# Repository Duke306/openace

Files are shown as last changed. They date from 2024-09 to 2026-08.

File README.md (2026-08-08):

# GATAS Conspicuity Device




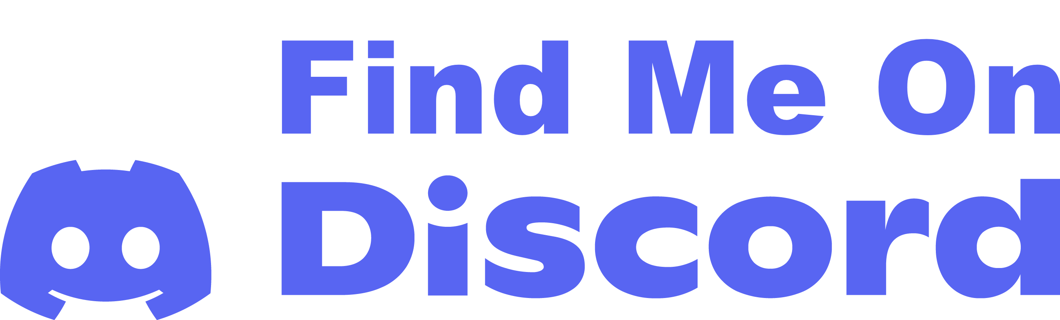
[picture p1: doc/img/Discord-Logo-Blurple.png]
[](https://discord.gg/J6mXTcWndS)

[📋 Changelog](./CHANGELOG.md) | [🎯 Wiki](https://rvt.github.io/gatas-doc/)

The GATAS Conspicuity device is designed for General Aviation pilots flying in areas where multiple
protocols, such as OGN, Flarm, ADS-L and FANET, are used. It can transmit and receive multiple
protocols simultaneously (excluding sending ADS-B) using one or more transceiver modules. All
received traffic is sent to your Electronic Flight Bag (EFB), such as SkyDemon, via the GDL90
protocol via WIFI or NMEA via bluetooth or WIFI.

The device is built around the Raspberry RP2040/RP2350 and can be configured with a custom PCB that
supports either two transceivers or a simpler configuration with one with modules from Waveshare
which makes it more of a plug-and-play. In both setups, it can send and receive all protocols using
time-sharing technology. The device can store configurations for multiple aircraft, which can be
selected through an easy-to-use web interface or via gatasServer

Powered by a Li-Ion battery, the device includes a PCB with a USB-C charger. The estimated battery
life is between 6 and 10 hours, though this is subject to further testing.

For FLARM it's current range has been t ested up to 24Km (see below screenshots) but on average a
good 15Km can be expected. This will give you plenty of time to avoid the traffic. EFBs like
SkyDemon can also send out audible traffic warnings.

Note: Although it's primary design is based around GA traffic, there is nothing in the hardware to
prevent other use cases like gliders, paragliders and hang gliders. The goal of the project is to be
seen by transmitting different protocols and be able to see them.

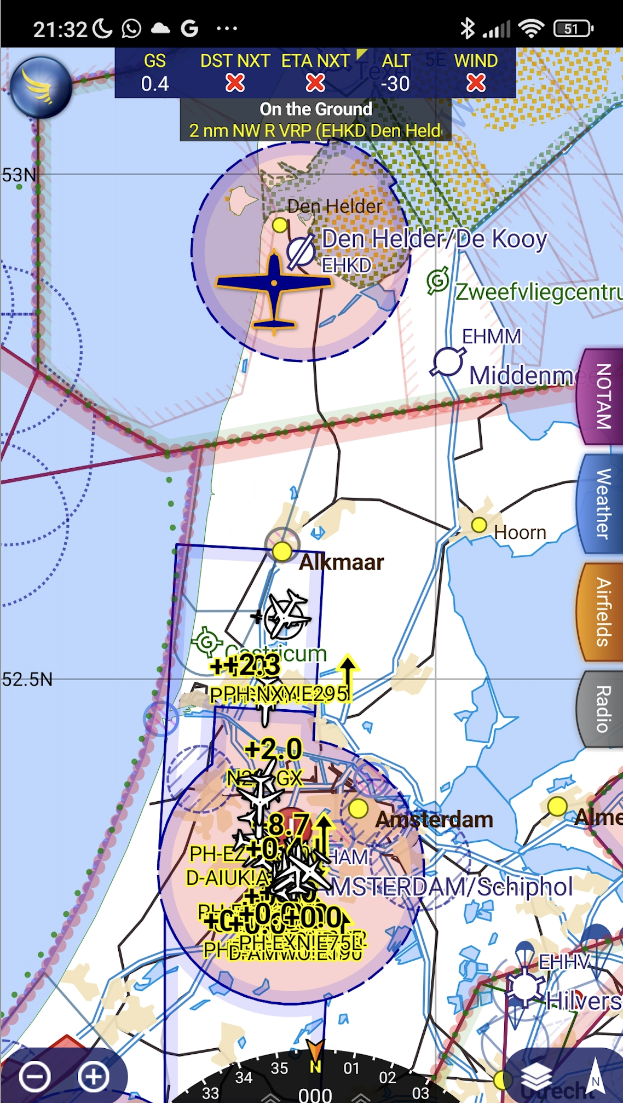
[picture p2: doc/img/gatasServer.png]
GATAS Server
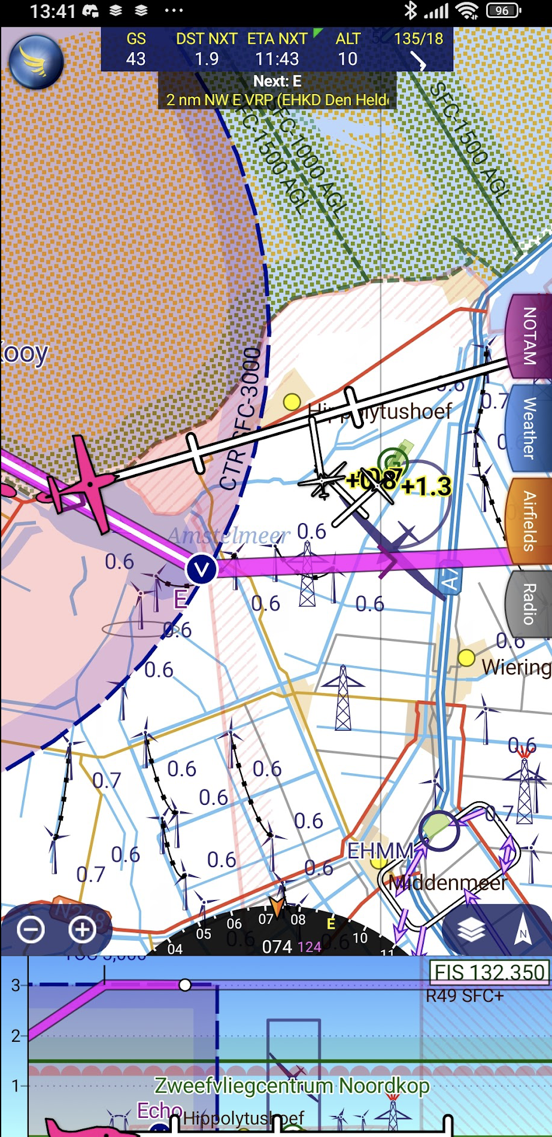
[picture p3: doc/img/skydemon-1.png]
Sky Demon)
| <br>Additional traffic via gatasServer |  <br> soaring planes directly via FLARM |
|---|---|
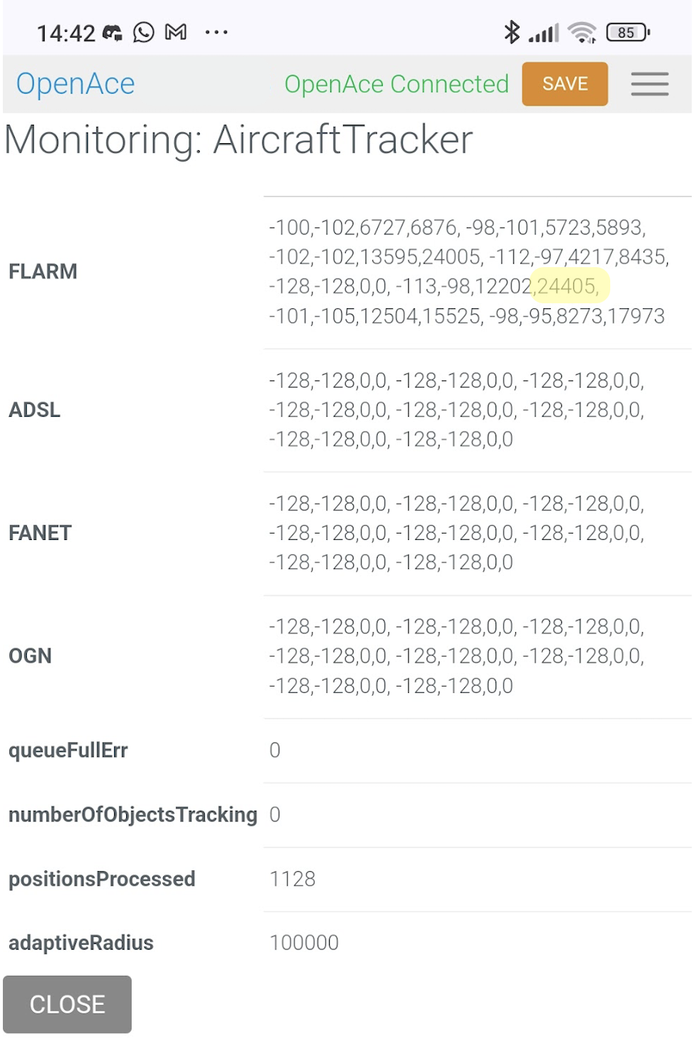
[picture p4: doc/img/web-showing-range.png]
Showing Range
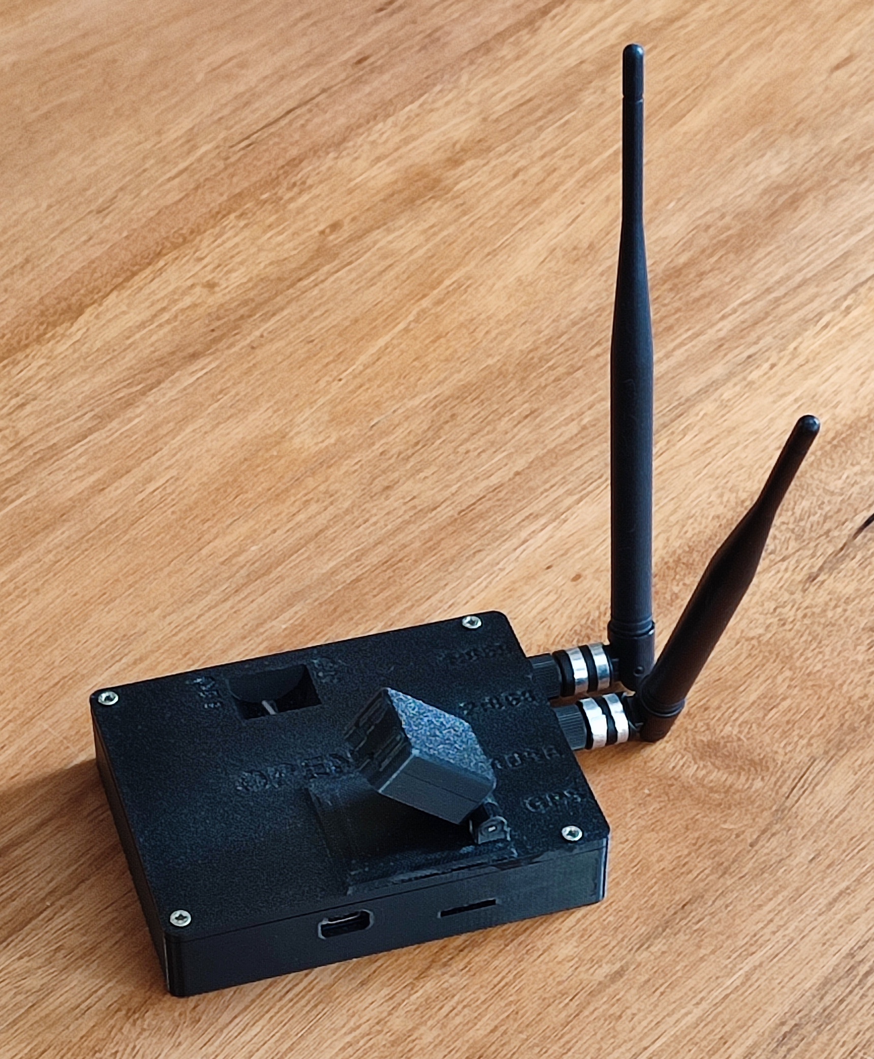
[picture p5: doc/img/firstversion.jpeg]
|  Showing range of 24Km | <br> Two Tranceiver Version I have been flying with |
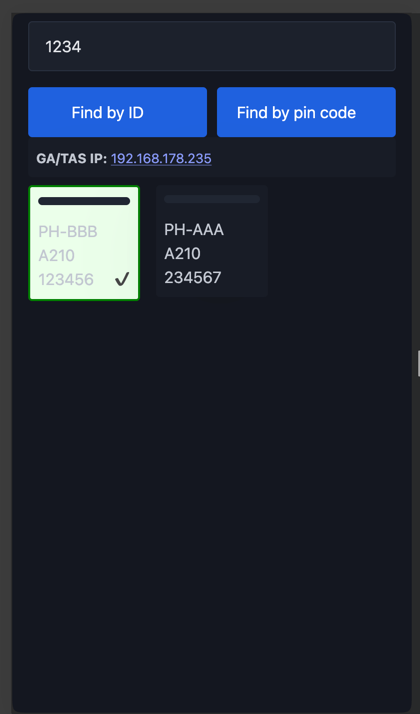
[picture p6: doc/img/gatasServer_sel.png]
Gatas Server
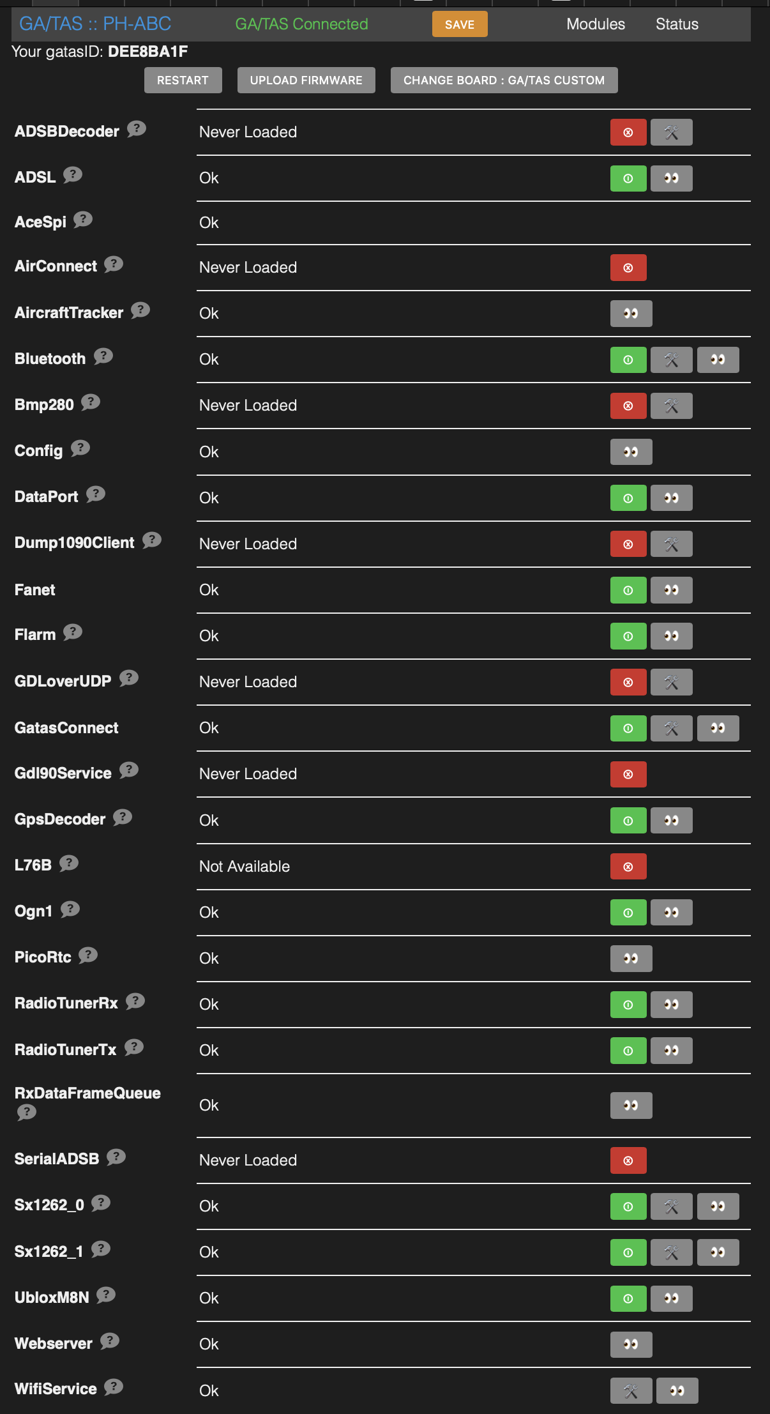
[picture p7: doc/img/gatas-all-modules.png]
All modules
|  <br> GATAS Server selecting Aircraft |  <br> All modules |
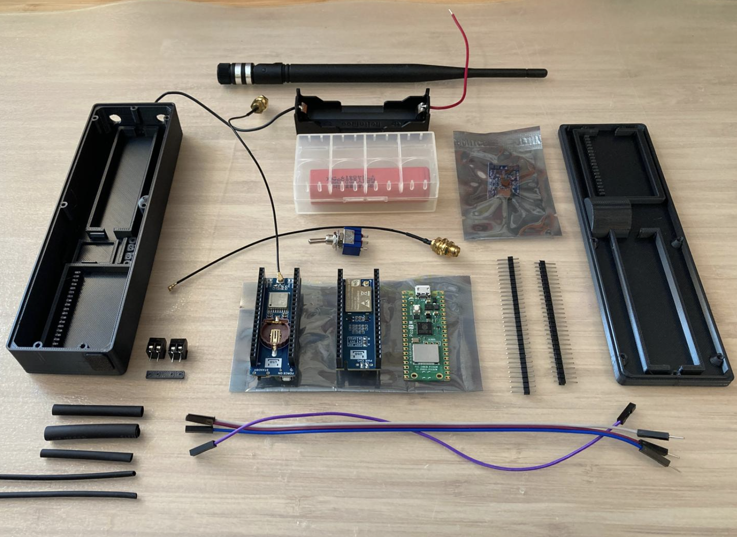
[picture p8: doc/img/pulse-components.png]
GATAS Pulse
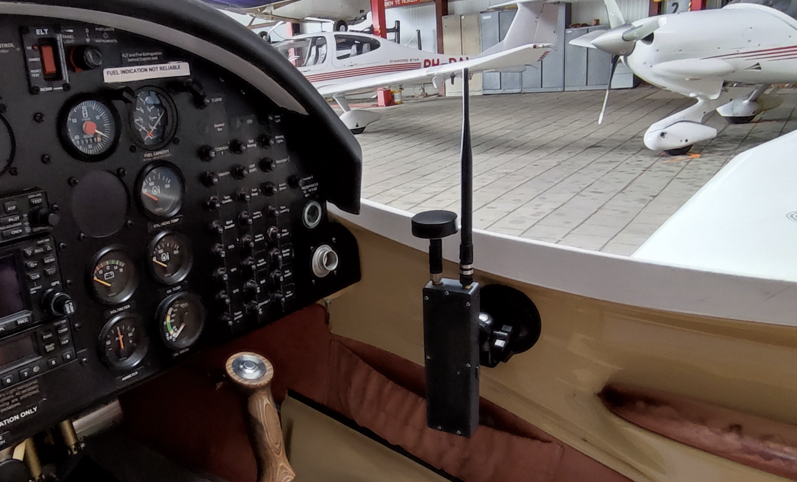
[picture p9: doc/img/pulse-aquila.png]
GATAS Pulse
|   <br> [GATAS Pulse Build Instructions](https://github.com/rvt/openace/wiki/gatas-Pulse) |  <br/> GATAS Pulse |

> [!NOTE]
> The screenshot of SkyDemon was taken from the car while driving for safety reasons. The screenshot
> of the web interface showing the 24Km was taken while parked and the device placed on top of the
> car
> for better air-2-air visibility.

## ADS-L Issue 2 — Ground Station Mode & Traffic Uplink

**New in 2.0.0**: GATAS now supports **ADS-L Issue 2** including ground station mode and traffic uplink. In ground
station mode the device not only transmits its own position but also re-broadcasts received traffic
back into the ADS-L network as uplink frames, making nearby traffic visible to other ADS-L
participants that would otherwise be out of range. This includes any traffic received via Gatas Connect and thus showing additional MLAT traffic.
This is ideal if you have glider fields and want to inform nearby traffic that a fields is active.
A maximum of 10 aircraft closest to the groundstation will be relayed.

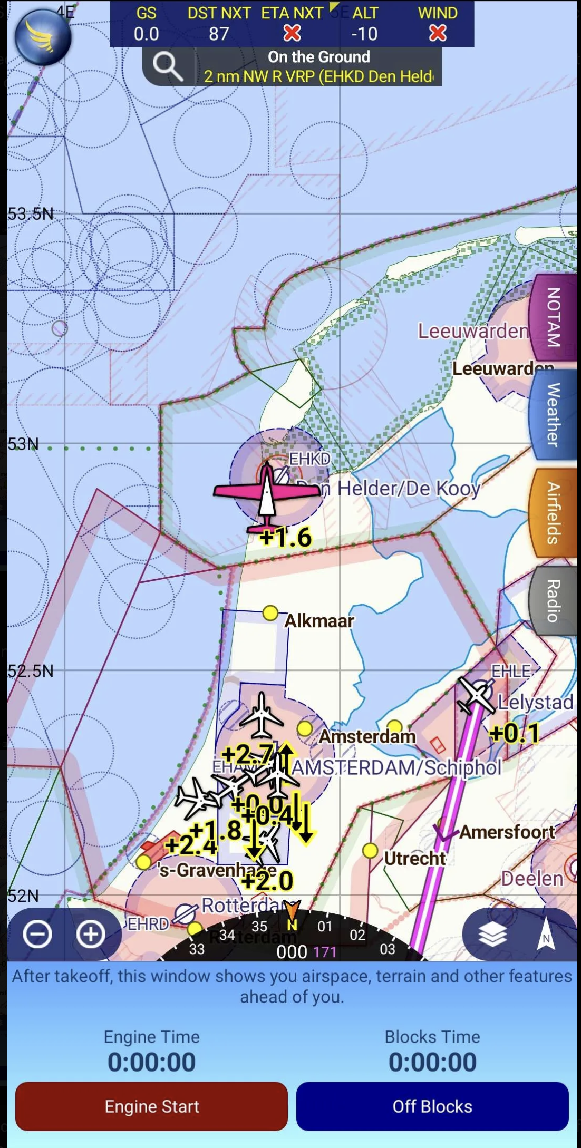
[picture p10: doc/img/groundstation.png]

Base station mode is active and relaying additional traffic.

## Radio Protocol Support

Radio Protocol is the method used to communicate with other conspicuity devices

| Radio Protocol. | Send | Receive | Multi Protocol |
|---|---|---|---|
| OGN | :heavy_check_mark: | :heavy_check_mark: | :heavy_check_mark: |
| ADS-L | :heavy_check_mark: | :heavy_check_mark: | :heavy_check_mark: |
| FLARM (2024) | :heavy_check_mark: | :heavy_check_mark: | :heavy_check_mark: |
| FANET | :heavy_check_mark: | :heavy_check_mark: | :heavy_check_mark: |
| ADS-B via gatasConnect | :no_entry: | :heavy_check_mark: | :heavy_minus_sign: |
| PAW (2026 uses ADS-L)  | :heavy_check_mark: | :heavy_check_mark: | :heavy_check_mark: |

\* Multi Protocol is a feature of GATAS that allows to enable multiple protocols both send and
receive on a single transceiver by sharing the air time. The Transceiver will alternate between the
different protocols and prioritize a specific protocol when it receives data for that protocol.

**Adaptive Protocol Prioritisation (New in 2.0.0)**: GATAS now intelligently allocates more listening slots
for protocols that are actively receiving traffic, increasing pings per aircraft and improving overall situational awareness.

- Fanet support sending and receving including forwaring of FANET messages
- gatasConnect is a protocol and service to receive additional traffic information via mobile
  connection.

\* PAW legacy protocol is not supported, only their new ADS-L version

### Communication support

Communication support is what protocols are supported to other devices like electronic flight bags
or other equipment.

| Protocol | Send UDP over WIFI | Receive UDP over WIFI | Send Bluetooth | Send TCP over WIFI | Receiver over TCP WIFI |
|---|---|---|---|---|---|
| GDL90 | :heavy_check_mark: | N/A | N/A | N/A | N/A |
| AirConnect | N/A | N/A | :heavy_check_mark: | :heavy_check_mark: | N/A |
| Dump1090 | N/A | N/A | N/A | N/A | :heavy_check_mark: |
| gatasConnect | :heavy_check_mark: | :heavy_check_mark: | N/A | N/A | :heavy_check_mark: |

\* Sending GDL90 over Bluetooth is not used in the industry so this is currently not setup. If this
is really required, then this can be done. Do let me know the use case

### Tested with Electronic Flight Bag

GATAS is currently tested with SkyDemon only, If you made it work with any other software on Phone
or Tablet, do let me know so I can add or help out to make this work.

| EFB | GDL90 over WIFI | Bluetooth | DataPort (NMEA) WIFI | Note |
|---|---|---|---|---|
| SkyDemon | :heavy_check_mark: | :heavy_check_mark: | :heavy_check_mark: | Tested Frequently during flight |
| EasyVFR 4 | :heavy_check_mark: | | | |
| ForeFlight | :heavy_check_mark: | | | With part of ForeFLight extended spec and auto discovery |
| XTrack | | :heavy_check_mark: | | Tested for connectivity |
| Air navigation | :heavy_check_mark: | | | Tested for connectivity |
| SeeYou Navigator | | :heavy_check_mark: | | GPS and traffic targets shown |

> [!INFO]
> Thanks to  [PocketFMS / EasyVFR](https://easyvfr4.aero/nl/) for providing a Developer license of EasyVFR 4 to help test GATAS GDL90
>

## gatasConnect & gatasServer

**gatasConnect** and **gatasServer** provide a lightweight UDP-based protocol for receiving
additional traffic information.
This is still somewhat experimental but up an running and usable, it's free for you to use on the pre-configured server. Just enable
'gatasConnect' and ensure GATAS does have internet access via your mobile dev ice. Configure **Client** mode to connect to
your mobile's access point, how cool is that!

> [!TIP]
> gatasConnect uses [https://airplanes.live](https://airplanes.live) to to deliver internet-based traffic to your GATAS
> and into your EFB, including ADS-B Out and MLAT-derived traffic.
> If you have the chance, please consider adding airplanes.live to your existing feed or creating a new one.
> By doing so, you help improve traffic coverage for yourself and for others and contribute to safer flying.
>

## Features

- Online web application to select your configured aircraft
- Eliminates the need to manually connect to GATAS vi WIFI to choose an aircraft, saves time and
  you can focus on flying.
- Still compatible with GATAS aircraft selection via **gatas build in web service**
- Future support for **automatic aircraft selection** based on correlated ADS-B traffic

### Network Usage

- **Transmit:** ~52 bytes/second
- **Receive:** ~1024 bytes/second at 30 aircraft. (supports up to 30 nearby aircraft)

## External Libraries and frameworks used

Most libraries are used 'as-is' Some of them have been slightly modified for performance reasons,
compatibility or other reasons.

1. Raspberry PI PICO
   SDK [https://github.com/raspberrypi/pico-sdk](https://github.com/raspberrypi/pico-sdk)
2. FreeRTOS, GATAS uses tasks and timers and avoids loops and runs in multi-core SMP
   mode. [https://www.freertos.org](https://www.freertos.org)
3. LWiP Pretty cool and sometimes confusing TCP/IP protocol
   suite [https://savannah.nongnu.org/projects/lwip/](https://savannah.nongnu.org/projects/lwip/)
4. ArduinoJSON for loading and storing
   configuration [https://arduinojson.org](https://arduinojson.org)
5. etlcpp pretty awesome library written by John
   Wellbelove [https://www.etlcpp.com](https://www.etlcpp.com)
6. libcrc [https://github.com/lammertb/libcrc](https://github.com/lammertb/libcrc)
7. minmea for parsing NMEA
   sentences [https://github.com/kosma/minmea/](https://github.com/kosma/minmea/)
8. Catch2 for unit testing [https://github.com/catchorg/Catch2](https://github.com/catchorg/Catch2)
8. Easy to use FANET implementation in
   C++ [https://github.com/rvt/FANET](https://github.com/rvt/FANET)

# GATAS Disclaimer

> [!IMPORTANT] > **Important Notice: Use at Your Own Risk**
>
> The GATAS Conspicuity Device is provided "as is," without any guarantees or warranties of any
> kind. By using this device, you acknowledge and agree that:
>
> 1. **No Warranty**: The creators of GATAS make no claims or guarantees regarding the accuracy,
     reliability, or fitness for a specific purpose of the device or its associated software. This
     includes, but is not limited to, communication with OGN, Flarm, ADS-L, or any other protocols.
> 2. **Assumption of Risk**: You assume full responsibility for any and all risks associated with
     the use of GATAS. This includes, but is not limited to, risks related to hardware
     malfunctions, software issues, or incorrect transmission/interpretation of data.
> 3. **Limitation of Liability**: Under no circumstances shall the creators, contributors, or
     affiliates of GATAS be held liable for any direct, indirect, incidental, or consequential
     damages resulting from the use, misuse, or inability to use the device or its software.
> 4. **General Aviation Use**: GATAS is intended for use in General Aviation environments where
     multiple protocols such as OGN, Flarm, and ADS-L are used. It is **not certified** for
     professional or commercial aviation use and should not be relied upon as the sole source of
     traffic or navigation information.
> 5. **Compliance**: Users are responsible for ensuring that the use of GATAS complies with local
     aviation regulations and requirements. It is your responsibility to ensure that the device
     operates within the legal limits and safety standards for your jurisdiction.
> 6. **IFR Use**: GATAS is not intended for usage during an IFR flight.
>
> By using GATAS, you agree to the terms of this disclaimer and acknowledge that you are using the
> device and its software at your own risk.

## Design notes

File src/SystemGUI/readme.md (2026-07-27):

# Overview

This directory, along with its subdirectories, contains the necessary files for developing components of the web interface for GATAS. If you're not working on the UI development, no additional steps are required—the C/C++ source files already integrate the web interface.

All files in the `SystemGUI/dist` directory are automatically packaged into `src/lib/webserver/gatas_fsdata.c`.

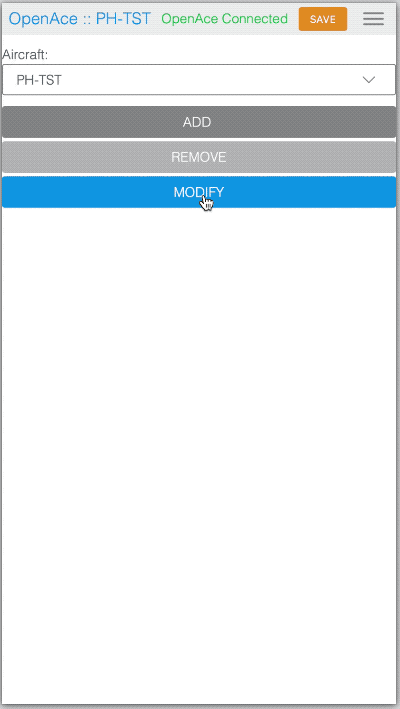
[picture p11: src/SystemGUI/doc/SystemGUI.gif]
GUI


# Libraries and frameworks used

1. `@frameable/el` LitElement-like framework to create and use web components [https://github.com/frameable/el](https://github.com/frameable/el)
1. `@picocss/pico` Lightweight semantic CSS framework, compiled with only the modules used by GATAS [https://picocss.com](https://picocss.com)
1. `just-validate` Form validation framework [https://just-validate.dev](https://just-validate.dev)

# Quick Start for UI Development

1. Ensure you have `npm` or `yarn` installed on your system, then run `npm install` in the `SystemGUI` directory.
2. Connect the GATAS hardware to your local network by enabling the `WifiService` and confgure GATAS to connect to your network
3. In the `.proxyrc.js` file, update the `target` variable with the device’s IP address. GATAS will print the IP address over Serial line USB or Debug mode
4. The UI will be accessible at `http://localhost:1234` if the device is running and connected to the network.
5. To start development, run `npm start`. Changes made to the code will be instantly reflected on the UI.
6. Once development is complete, run `npm run build` to generate a distribution in the `dist` directory. Rebuilding GATAS with `cmake` will include the necessary UI files.

# Unit Tests

1. Frontend unit tests live in `test/`.
2. Run tests with `npm test` from `src/SystemGUI`.
3. Add new tests using the `*.test.mjs` naming pattern.

# Files

- `.proxyrc.js` proxy setting to direct API calls to GATAS for hot re-loading en testing of the UI
- `.parcelrcrelease` Release configuration using in the build process to compress using gzip
- `package.json` npm package file
- `src` Directory containing the project files with css and various components

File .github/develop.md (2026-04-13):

# Development version {{VERSION}}

This is the **DEVELOPMENT** version of GATAS, use at your own risk

> [!TIP]
> **GATAS is an ongoing project** that is continuously being developed and improved.
> As a result, features, functionality, and performance may be updated or modified at any time without prior notice.
> We value feedback and collaboration!
> If you have any questions, suggestions, or concerns, feel free to reach out.
> Your input helps us improve the project and ensure it meets the needs of the community.

> [!IMPORTANT]
> **Disclaimer: Use at Your Own Risk**
>
> GATAS is provided "as is," without any warranties.
> By downloading or using this device, you acknowledge that you do so at your own risk.
> The creators are not liable for any damages or issues resulting from its use.
> GATAS is intended for General Aviation only and should not be relied upon as the sole source of traffic or navigation information.
> Users are responsible for ensuring compliance with local aviation regulations.

## In this release

{{CHANGELOG}}

## How to Copy the UF2 File to the Raspberry Pi Pico

### 1. Download the `GATAS_rp2040.uf2` or `GATAS_rp2350-arm-s.uf2` File
- Obtain the correct firmware suitable for your PICO from [https://github.com/rvt/openace/releases](https://github.com/rvt/openace/releases)
- Make sure you know where the file is saved on your computer.

### 2. Connect Raspberry Pi Pico to Your Computer
- **Hold down the BOOTSEL button** on your Raspberry Pi Pico.
- While holding the BOOTSEL button, **connect the Pico to your computer** using a USB cable.
- Once connected, release the BOOTSEL button.

### 3. Raspberry Pi Pico in USB Mass Storage Mode
- Your Pico will appear as a **USB mass storage device** on your computer (e.g., as `RPI-RP2`).
    - On **Windows**, it will appear as a removable drive.
    - On **macOS** and **Linux**, it will appear as an external drive.

### 4. Copy `GATAS_*.uf2` File to the Pico
- Open the `RPI-RP2` drive.
- **Drag and drop** or **copy and paste** the `GATAS_*.uf2` file into the Pico's drive.
    - Do **not** try to open or modify the `GATAS_*.uf2` file; simply copy it.

### 5. Automatic Reboot
- After the file is copied, the Pico will **automatically reboot** and run the new firmware.
- The Pico will disappear from your list of drives, indicating that the flashing process is complete.

### 6. Verify the Installation
- Once rebooted, the Pico will start running the newly flashed firmware, it should show a green flasing led

## Troubleshooting
- **If the Pico does not show up as a USB drive**:
    - Ensure you are holding the BOOTSEL button while connecting it to the computer.
    - Try using a different USB cable (some cables only provide power and don't support data transfer).

## Summary
1. Download the `GATAS_*.uf2` file.
2. Hold down the BOOTSEL button and connect the Pico to your computer.
3. Release the BOOTSEL button once connected.
4. Copy the `GATAS_*.uf2` file to the Pico's mass storage drive.
5. The Pico will reboot automatically, running the new firmware.
6. The green LED on the PICO will start flashing once a second

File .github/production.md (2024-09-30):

# Production version

This is the **PRODUCTION** version of OpenAce, use at your own risk

> [!TIP]
> **OpenAce is an ongoing project** that is continuously being developed and improved. 
> As a result, features, functionality, and performance may be updated or modified at any time without prior notice.
> We value feedback and collaboration! 
> If you have any questions, suggestions, or concerns, feel free to reach out. 
> Your input helps us improve the project and ensure it meets the needs of the community.

> [!IMPORTANT]
> **Disclaimer: Use at Your Own Risk**
> 
> OpenAce is provided "as is," without any warranties. 
> By downloading or using this device, you acknowledge that you do so at your own risk. 
> The creators are not liable for any damages or issues resulting from its use. 
> OpenAce is intended for General Aviation only and should not be relied upon as the sole source of traffic or navigation information. 
> Users are responsible for ensuring compliance with local aviation regulations.

## How to Copy the UF2 File to the Raspberry Pi Pico

### 1. Download the `OpenAce.uf2` File
- Obtain the `OpenAce.uf2` file from [https://github.com/rvt/OpenAce/release](https://github.com/rvt/OpenAce/release)
- Make sure you know where the file is saved on your computer.

### 2. Connect Raspberry Pi Pico to Your Computer
- **Hold down the BOOTSEL button** on your Raspberry Pi Pico.
- While holding the BOOTSEL button, **connect the Pico to your computer** using a USB cable.
- Once connected, release the BOOTSEL button.

### 3. Raspberry Pi Pico in USB Mass Storage Mode
- Your Pico will appear as a **USB mass storage device** on your computer (e.g., as `RPI-RP2`).
    - On **Windows**, it will appear as a removable drive.
    - On **macOS** and **Linux**, it will appear as an external drive.

### 4. Copy `OpenAce.uf2` File to the Pico
- Open the `RPI-RP2` drive.
- **Drag and drop** or **copy and paste** the `OpenAce.uf2` file into the Pico's drive.
    - Do **not** try to open or modify the `OpenAce.uf2` file; simply copy it.

### 5. Automatic Reboot
- After the file is copied, the Pico will **automatically reboot** and run the new firmware.
- The Pico will disappear from your list of drives, indicating that the flashing process is complete.

### 6. Verify the Installation
- Once rebooted, the Pico will start running the newly flashed firmware, it should show a green flasing led

## Troubleshooting
- **If the Pico does not show up as a USB drive**:
    - Ensure you are holding the BOOTSEL button while connecting it to the computer.
    - Try using a different USB cable (some cables only provide power and don't support data transfer).

## Summary
1. Download the `OpenAce.uf2` file.
2. Hold down the BOOTSEL button and connect the Pico to your computer.
3. Release the BOOTSEL button once connected.
4. Copy the `OpenAce.uf2` file to the Pico's mass storage drive.
5. The Pico will reboot automatically, running the new firmware.
6. The green LED on the PICO will start flashing once a second

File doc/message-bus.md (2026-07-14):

# OpenAce Message Bus

This document maps every message type to its sender(s) and receiver(s).

> **Maintenance note**: Keep this document split into separate flow diagrams. When updating it, change only the affected flow sections and do not collapse everything into one large combined flow unless explicitly asked.

> **How this was generated**: Senders were found by grepping `getBus().receive(` across all `.cpp` files. Receivers were found by grepping `void on_receive(const GATAS::` across all `.hpp` files. The class name was inferred from the enclosing file/class context.

> **Direct handoff note**: Some important current flows are shown even though they are not plain bus publishes, notably `Dump1090Client -> ADSBDecoder` and `Sx1262 -> RxDataFrameQueue`.

## Bus Semantics

- The firmware uses `GATAS::ThreadSafeBus<24>` from `src/lib/core/ace/messagerouter.hpp`.
- Dispatch is synchronous: publishers call `getBus().receive(...)` and the ETL bus delivers directly to subscribers.
- The bus itself does not queue or copy messages.
- `etl::shared_message` is technically supported but explicitly warned against.
- Some important data paths are not bus messages at all; those are called out below.

## Module Topology

```plantuml
' =====================================================================
' SYSTEM OVERVIEW
' =====================================================================
@startuml
title System Overview

left to right direction

rectangle "GPS Subsystem" {
    [AbstractGnss]
    [GpsDecoder]
}

rectangle "Radio Subsystem" {
    [Sx1262]
    [RxDataFrameQueue]
    [RadioTunerRx]
    [RadioTunerTx]
}

rectangle "ADSB Input" {
    [Dump1090Client]
}

rectangle "Protocols" {
    [Ogn1]
    [Flarm2024]
    [ADSLAce]
    [FanetAce]
    [ADSBDecoder]
}

rectangle "Tracking" {
    [AircraftTracker]
}

rectangle "Outputs" {
    [Gdl90Service]
    [GDLoverUDP]
    [DataPort]
    [GatasConnect]
    [GatasConnectUDP]
    [Bluetooth]
    [AirConnect]
}

rectangle "Infrastructure" {
    [Idle]
    [Config]
    [WifiService]
    [Bmp280]
    [PicoRtc]
}

[AbstractGnss] --> [GpsDecoder] : GPSSentenceMsg
[GpsDecoder] --> [Ogn1] : OwnshipPositionMsg
[GpsDecoder] --> [Flarm2024] : OwnshipPositionMsg
[GpsDecoder] --> [ADSLAce] : OwnshipPositionMsg
[GpsDecoder] --> [FanetAce] : OwnshipPositionMsg
[GpsDecoder] --> [ADSBDecoder] : OwnshipPositionMsg
[GpsDecoder] --> [AircraftTracker] : OwnshipPositionMsg
[GpsDecoder] --> [RadioTunerRx] : OwnshipPositionMsg
[GpsDecoder] --> [RadioTunerTx] : OwnshipPositionMsg
[GpsDecoder] --> [GatasConnect] : OwnshipPositionMsg\nGpsStatsMsg
[GpsDecoder] --> [PicoRtc] : UtcTimeMsg
[Sx1262] --> [RxDataFrameQueue]
[RxDataFrameQueue] --> [Ogn1] : RadioRxManchesterMsg
[RxDataFrameQueue] --> [Flarm2024] : RadioRxManchesterMsg
[RxDataFrameQueue] --> [ADSLAce] : RadioRxManchesterMsg\nRadioRxMsg
[RxDataFrameQueue] --> [FanetAce] : RadioRxMsg
[Dump1090Client] ..> [ADSBDecoder] : ADS-B binary\n(direct receiveBinary)
[Ogn1] --> [AircraftTracker] : IngressAircraftPositionMsg
[Flarm2024] --> [AircraftTracker] : IngressAircraftPositionMsg
[ADSLAce] --> [AircraftTracker] : IngressAircraftPositionMsg\nIngressAircraftPositionsMsg
[FanetAce] --> [AircraftTracker] : IngressAircraftPositionMsg
[ADSBDecoder] --> [AircraftTracker] : IngressAircraftPositionMsg
[AircraftTracker] --> [Gdl90Service] : EgressAircraftPositionMsg
[AircraftTracker] --> [DataPort] : EgressAircraftPositionMsg
[AircraftTracker] --> [ADSLAce] : EgressAircraftPositionsMsg
[AircraftTracker] --> [ADSBDecoder] : AdapativeRadiusMsg
[RadioTunerRx] --> [Sx1262] : RadioControlMsg
[RadioTunerRx] --> [RadioTunerTx] : RadioControlMsg
[RadioTunerTx] --> [Ogn1] : RadioTxPositionRequestMsg
[RadioTunerTx] --> [Flarm2024] : RadioTxPositionRequestMsg
[RadioTunerTx] --> [ADSLAce] : RadioTxPositionRequestMsg
[RadioTunerTx] --> [FanetAce] : RadioTxPositionRequestMsg
[RadioTunerTx] --> [AircraftTracker] : RadioTxPositionRequestMsg
[Gdl90Service] --> [GDLoverUDP] : GdlMsg
[Gdl90Service] --> [GatasConnect] : GdlMsg
[GatasConnect] --> [GatasConnectUDP] : GatasConnectTx
[GatasConnect] --> [Bluetooth] : GatasConnectTx
[GatasConnectUDP] --> [GatasConnect] : GatasConnectRx
[DataPort] --> [Bluetooth] : DataPortMsg
[DataPort] --> [AirConnect] : DataPortMsg
[Bmp280] --> [Ogn1] : BarometricPressureMsg

@enduml
```

```plantuml
' =====================================================================
' GPS DATA FLOW
' =====================================================================
@startuml
title GPS Data Flow

left to right direction

package "GPS" {
    [AbstractGnss]
    [GpsDecoder]
    [PicoRtc]
}

package "Consumers" {
    package "Protocols" {
        [Ogn1]
        [Flarm2024]
        [ADSLAce]
        [FanetAce]
        [ADSBDecoder]
    }
    [RadioTunerRx]
    [RadioTunerTx]
    [Gdl90Service]
    [DataPort]
    [GatasConnect]
    [Bluetooth]
    [Sx1262]
    [Idle]
}

[AbstractGnss] --> [GpsDecoder] : GPSSentenceMsg
[GpsDecoder] --> [Ogn1] : OwnshipPositionMsg\nGpsStatsMsg
[GpsDecoder] --> [Flarm2024] : OwnshipPositionMsg
[GpsDecoder] --> [ADSLAce] : OwnshipPositionMsg\nGpsStatsMsg
[GpsDecoder] --> [FanetAce] : OwnshipPositionMsg
[GpsDecoder] --> [ADSBDecoder] : OwnshipPositionMsg
[GpsDecoder] --> [AircraftTracker] : OwnshipPositionMsg
[GpsDecoder] --> [RadioTunerRx] : OwnshipPositionMsg
[GpsDecoder] --> [RadioTunerTx] : OwnshipPositionMsg
[GpsDecoder] --> [Gdl90Service] : OwnshipPositionMsg\nGpsStatsMsg
[GpsDecoder] --> [DataPort] : OwnshipPositionMsg
[GpsDecoder] --> [GatasConnect] : OwnshipPositionMsg\nGpsStatsMsg
[GpsDecoder] --> [Bluetooth] : OwnshipPositionMsg
[GpsDecoder] --> [Sx1262] : GpsStatsMsg
[GpsDecoder] --> [Idle] : GpsStatsMsg

[GpsDecoder] --> [PicoRtc] : UtcTimeMsg

[AbstractGnss] --> [DataPort] : GPSSentenceMsg

@enduml
```

```plantuml

' =====================================================================
' RADIO RX FLOW
' =====================================================================
@startuml
title Radio RX Flow

left to right direction

package "Radio" {
    [Sx1262]
    [RxDataFrameQueue]
    [RadioTunerRx]
}

package "ADSB Input" {
    [Dump1090Client]
}

package "Protocol Decoders" {
    [Ogn1]
    [Flarm2024]
    [ADSLAce]
    [FanetAce]
    [ADSBDecoder]
}

package "Tracking" {
    [AircraftTracker]
    [RadioTunerRx] as RTRx2
}

package "Monitoring" {
    [GatasConnect]
}

[RadioTunerRx] --> [Sx1262] : RadioControlMsg
[Sx1262] --> [RxDataFrameQueue]
[RxDataFrameQueue] --> [Ogn1] : RadioRxManchesterMsg
[RxDataFrameQueue] --> [Flarm2024] : RadioRxManchesterMsg
[RxDataFrameQueue] --> [ADSLAce] : RadioRxManchesterMsg\nRadioRxMsg
[RxDataFrameQueue] --> [FanetAce] : RadioRxMsg
[Dump1090Client] ..> [ADSBDecoder] : ADS-B binary\n(direct receiveBinary)

[Ogn1] --> [AircraftTracker] : IngressAircraftPositionMsg
[Flarm2024] --> [AircraftTracker] : IngressAircraftPositionMsg
[ADSLAce] --> [AircraftTracker] : IngressAircraftPositionMsg\nIngressAircraftPositionsMsg
[FanetAce] --> [AircraftTracker] : IngressAircraftPositionMsg
[ADSBDecoder] --> [AircraftTracker] : IngressAircraftPositionMsg
[GpsDecoder] --> [AircraftTracker] : OwnshipPositionMsg

note bottom of GatasConnect : GatasConnect also receives\nIngressAircraftPositionMsg\nfor radio-traffic awareness

note bottom of RTRx2 : RadioTunerRx also receives\nIngressAircraftPositionMsg\nfor traffic-biased scheduling

@enduml
```

```plantuml
' =====================================================================
' TRACKING AND OUTPUT
' =====================================================================
@startuml
title Aircraft Tracking and Output

left to right direction

[AircraftTracker]

package "Protocol Feedback" {
    [ADSLAce]
    [ADSBDecoder]
}

package "Output Services" {
    [Gdl90Service]
    [GDLoverUDP]
    [DataPort]
    [GatasConnect]
    [GatasConnectUDP]
    [Bluetooth]
    [AirConnect]
}

[AircraftTracker] --> [Gdl90Service] : EgressAircraftPositionMsg
[AircraftTracker] --> [DataPort] : EgressAircraftPositionMsg
[AircraftTracker] --> [ADSLAce] : EgressAircraftPositionsMsg
[AircraftTracker] --> [ADSBDecoder] : AdapativeRadiusMsg

[Gdl90Service] --> [GDLoverUDP] : GdlMsg
[Gdl90Service] --> [GatasConnect] : GdlMsg

[GatasConnect] --> [GatasConnectUDP] : GatasConnectTx
[GatasConnect] --> [Bluetooth] : GatasConnectTx
[GatasConnectUDP] --> [GatasConnect] : GatasConnectRx
[DataPort] --> [Bluetooth] : DataPortMsg
[Bluetooth] --> [GatasConnect] : GatasConnectRx
[Bluetooth] --> [AirConnect] : DataPortMsg
[DataPort] --> [AirConnect] : DataPortMsg

@enduml
```

```plantuml
' =====================================================================
' RADIO TX FLOW
' =====================================================================
@startuml
title Radio TX Flow

left to right direction

package "Radio Control" {
    [RadioTunerTx]
    [RadioTunerRx]
}

package "Protocols" {
    [Ogn1]
    [Flarm2024]
    [ADSLAce]
    [FanetAce]
}

package "Tracking" {
    [AircraftTracker]
}

package "Radio Hardware" {
    [Sx1262]
}

[RadioTunerRx] --> [Sx1262] : RadioControlMsg
[RadioTunerRx] --> [RadioTunerTx] : RadioControlMsg
[RadioTunerTx] --> [Ogn1] : RadioTxPositionRequestMsg
[RadioTunerTx] --> [Flarm2024] : RadioTxPositionRequestMsg
[RadioTunerTx] --> [ADSLAce] : RadioTxPositionRequestMsg
[RadioTunerTx] --> [FanetAce] : RadioTxPositionRequestMsg
[RadioTunerTx] --> [AircraftTracker] : RadioTxPositionRequestMsg

[Ogn1] --> [Sx1262] : RadioTxFrameMsg
[Flarm2024] --> [Sx1262] : RadioTxFrameMsg
[ADSLAce] --> [Sx1262] : RadioTxFrameMsg
[FanetAce] --> [Sx1262] : RadioTxFrameMsg

@enduml
```

```plantuml
' =====================================================================
' SENSOR FLOW
' =====================================================================
@startuml
title Sensor Data Flow

left to right direction

[Bmp280] --> [Ogn1] : BarometricPressureMsg

@enduml
```

```plantuml
' =====================================================================
' TIMER / CONFIG / WIFI
' =====================================================================
@startuml
title Infrastructure Messages

left to right direction

package "Timers" {
    [Idle]
}

package "Configuration" {
    [Config]
}

package "Network" {
    [WifiService]
    [GatasConnect] as GC4
}

package "Timer Consumers" {
    [ADSBDecoder]
    [WifiService] as WS2
    [AirConnect]
    [AircraftTracker]
    [Bmp280]
    [DataPort]
}

package "Config Consumers" {
    [Sx1262]
    [GDLoverUDP]
    [Ogn1]
    [ADSLAce]
    [FanetAce]
    [ADSBDecoder] as AD2
    [GpsDecoder]
    [GatasConnect] as GC2
    [GatasConnectUDP]
    [RadioTunerRx]
    [RadioTunerTx]
    [AircraftTracker] as AT2
    [Gdl90Service]
    [Bmp280] as BMP2
}

package "Wifi Consumers" {
    [GatasConnect] as GC3
    [GatasConnectUDP] as GU2
    [GDLoverUDP] as GO2
    [DataPort] as DP2
    [Dump1090Client]
    [AirConnect] as AC2
    [Idle] as I2
}

[Idle] --> [ADSBDecoder] : Every5SecMsg
[Idle] --> [WS2] : Every5SecMsg
[Idle] --> [AirConnect] : Every5SecMsg
[Idle] --> [AircraftTracker] : Every5SecMsg
[Idle] --> [Bmp280] : Every30SecMsg
[Idle] --> [DataPort] : Every30SecMsg

[Config] --> [Sx1262] : ConfigUpdatedMsg
[Config] --> [GDLoverUDP] : ConfigUpdatedMsg
[Config] --> [Ogn1] : ConfigUpdatedMsg
[Config] --> [ADSLAce] : ConfigUpdatedMsg
[Config] --> [FanetAce] : ConfigUpdatedMsg
[Config] --> [AD2] : ConfigUpdatedMsg
[Config] --> [GpsDecoder] : ConfigUpdatedMsg
[Config] --> [GC2] : ConfigUpdatedMsg
[Config] --> [GatasConnectUDP] : ConfigUpdatedMsg
[Config] --> [RadioTunerRx] : ConfigUpdatedMsg
[Config] --> [RadioTunerTx] : ConfigUpdatedMsg
[Config] --> [AT2] : ConfigUpdatedMsg
[Config] --> [Gdl90Service] : ConfigUpdatedMsg
[Config] --> [BMP2] : ConfigUpdatedMsg

[GC4] --> [WifiService] : WifiModeRequestMsg
[WifiService] --> [GC3] : WifiConnectionStateMsg
[WifiService] --> [GU2] : WifiConnectionStateMsg
[WifiService] --> [GO2] : WifiConnectionStateMsg\nAccessPointClientsMsg
[WifiService] --> [DP2] : WifiConnectionStateMsg
[WifiService] --> [Dump1090Client] : WifiConnectionStateMsg
[WifiService] --> [AC2] : WifiConnectionStateMsg
[WifiService] --> [I2] : WifiConnectionStateMsg

@enduml
```

## Active Message Map

| Message | Publisher(s) | Subscriber(s) | Notes |
| --- | --- | --- | --- |
| `GPSSentenceMsg` | `AbstractGnss` | `GpsDecoder`, `DataPort` | Raw NMEA ingress. |
| `OwnshipPositionMsg` | `GpsDecoder` | `Ogn1`, `Flarm2024`, `ADSLAce`, `FanetAce`, `ADSBDecoder`, `AircraftTracker`, `RadioTunerRx`, `RadioTunerTx`, `Gdl90Service`, `DataPort`, `Bluetooth`, `GatasConnect` | Main ownship state fan-out. |
| `UtcTimeMsg` | `GpsDecoder` | `PicoRtc` | RTC synchronization. |
| `GpsStatsMsg` | `GpsDecoder` | `Ogn1`, `ADSLAce`, `Sx1262`, `Gdl90Service`, `GatasConnect`, `Idle` | GPS fix and DOP status. |
| `BarometricPressureMsg` | `Bmp280` | `Ogn1` | OGN transmission enhancement. |
| `RadioRxManchesterMsg` | `RxDataFrameQueue` | `Ogn1`, `Flarm2024`, `ADSLAce` | Produced after `Sx1262` receive + Manchester decode. |
| `RadioRxMsg` | `RxDataFrameQueue` | `ADSLAce`, `FanetAce` | Produced after `Sx1262` receive for non-Manchester frames. |
| `IngressAircraftPositionMsg` | `Ogn1`, `Flarm2024`, `ADSLAce`, `FanetAce`, `ADSBDecoder` | `AircraftTracker`, `RadioTunerRx`, `GatasConnect` | Single aircraft decoded from any protocol. |
| `IngressAircraftPositionsMsg` | `ADSLAce` | `AircraftTracker` | Batched ADS-L uplink traffic. |
| `EgressAircraftPositionMsg` | `AircraftTracker` | `Gdl90Service`, `DataPort` | Tracker-selected traffic for outputs. |
| `EgressAircraftPositionsMsg` | `AircraftTracker` | `ADSLAce` | Tracker-selected batch for ADS-L transmit. |
| `AdapativeRadiusMsg` | `AircraftTracker` | `ADSBDecoder` | Decoder radius feedback. |
| `RadioControlMsg` | `RadioTunerRx` | `Sx1262`, `RadioTunerTx` | Current receive slot / radio assignment. |
| `RadioTxPositionRequestMsg` | `RadioTunerTx` | `Ogn1`, `Flarm2024`, `ADSLAce`, `FanetAce`, `AircraftTracker` | Triggers per-protocol transmit preparation. |
| `RadioTxFrameMsg` | `Ogn1`, `Flarm2024`, `ADSLAce`, `FanetAce` | `Sx1262` | Final frame sent to RF hardware. |
| `DataPortMsg` | `DataPort`, `Bluetooth` | `AirConnect`, `Bluetooth` | NMEA-compatible egress and BLE NMEA ingress. |
| `GdlMsg` | `Gdl90Service` | `GDLoverUDP`, `GatasConnect` | Packed GDL90 bytes for network and bridge outputs. |
| `GatasConnectTx` | `GatasConnect` | `GatasConnectUDP`, `Bluetooth` | Framed binary output, transport-agnostic. |
| `GatasConnectRx` | `GatasConnectUDP`, `Bluetooth` | `GatasConnect` | Framed binary input from transports. |
| `WifiModeRequestMsg` | `GatasConnect` | `WifiService` | Companion-originated WiFi mode switch request derived from framed binary control traffic. |
| `WifiConnectionStateMsg` | `WifiService` | `Dump1090Client`, `GDLoverUDP`, `GatasConnect`, `GatasConnectUDP`, `DataPort`, `AirConnect`, `Idle` | Shared network state. |
| `AccessPointClientsMsg` | `WifiService` | `GDLoverUDP` | AP client list for UDP output policy. |
| `ConfigUpdatedMsg` | `Config` | `GpsDecoder`, `Bmp280`, `Sx1262`, `Ogn1`, `ADSLAce`, `FanetAce`, `ADSBDecoder`, `AircraftTracker`, `RadioTunerRx`, `RadioTunerTx`, `Gdl90Service`, `GDLoverUDP`, `GatasConnect`, `GatasConnectUDP` | Runtime config propagation. |
| `Every5SecMsg` | `Idle` | `WifiService`, `AirConnect`, `ADSBDecoder`, `AircraftTracker` | Periodic maintenance. |
| `Every30SecMsg` | `Idle` | `Bmp280`, `DataPort` | Slow periodic maintenance. |

## Messages Currently Defined But Not Active In The Main Flow

| Message | Current status |
| --- | --- |
| `ADSBMessageBinMsg` | Supported by `ADSBDecoder`, but the current `Dump1090Client` path calls `ADSBDecoder::receiveBinary(...)` directly instead of publishing to the bus. |
| `Every1SecMsg` | Emitted by `Idle`, but there are no current subscribers. |
| `Every15SecMsg` | Emitted by `Idle`, but there are no current subscribers. |
| `Every300SecMsg` | Emitted by `Idle`, but there are no current subscribers. |
| `IdleMsg` | Emitted by `Idle`, but there are no current subscribers. |

## Important Non-Bus Paths

- `Dump1090Client -> ADSBDecoder` is a direct call through `BinaryReceiver::receiveBinary(...)`, not a bus message.
- `Sx1262 -> RxDataFrameQueue` uses an internal queue/task handoff before frames become `RadioRxManchesterMsg` or `RadioRxMsg`.
- `Bluetooth` can inject `DataPortMsg` and `GatasConnectRx` into the bus from BLE characteristics.
- `Webserver`, `AceSpi`, and `SerialADSB` are loaded modules, but they are not meaningful bus routers in the current topology.

## Updating This Document

When the topology changes, verify all three of these:

1. Publishers: `rg -n "getBus\\(\\)\\.receive\\(|sendToBus\\(" src/lib src/pico`
2. Subscribers: `rg -n "void on_receive\\(const GATAS::" src/lib`
3. Router declarations: `rg -n "message_router<" src/lib`

Also check for direct module-to-module calls like `receiveBinary(...)`, because those will not appear in a pure bus grep but still affect the effective data flow.

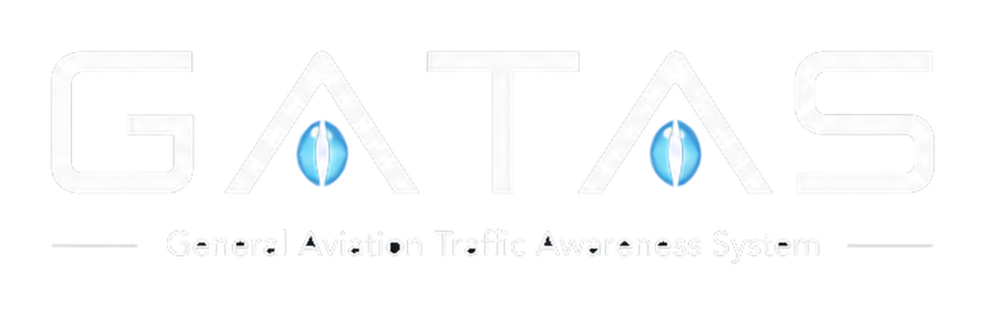
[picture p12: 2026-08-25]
doc/media/gatas-dark-tagline.png

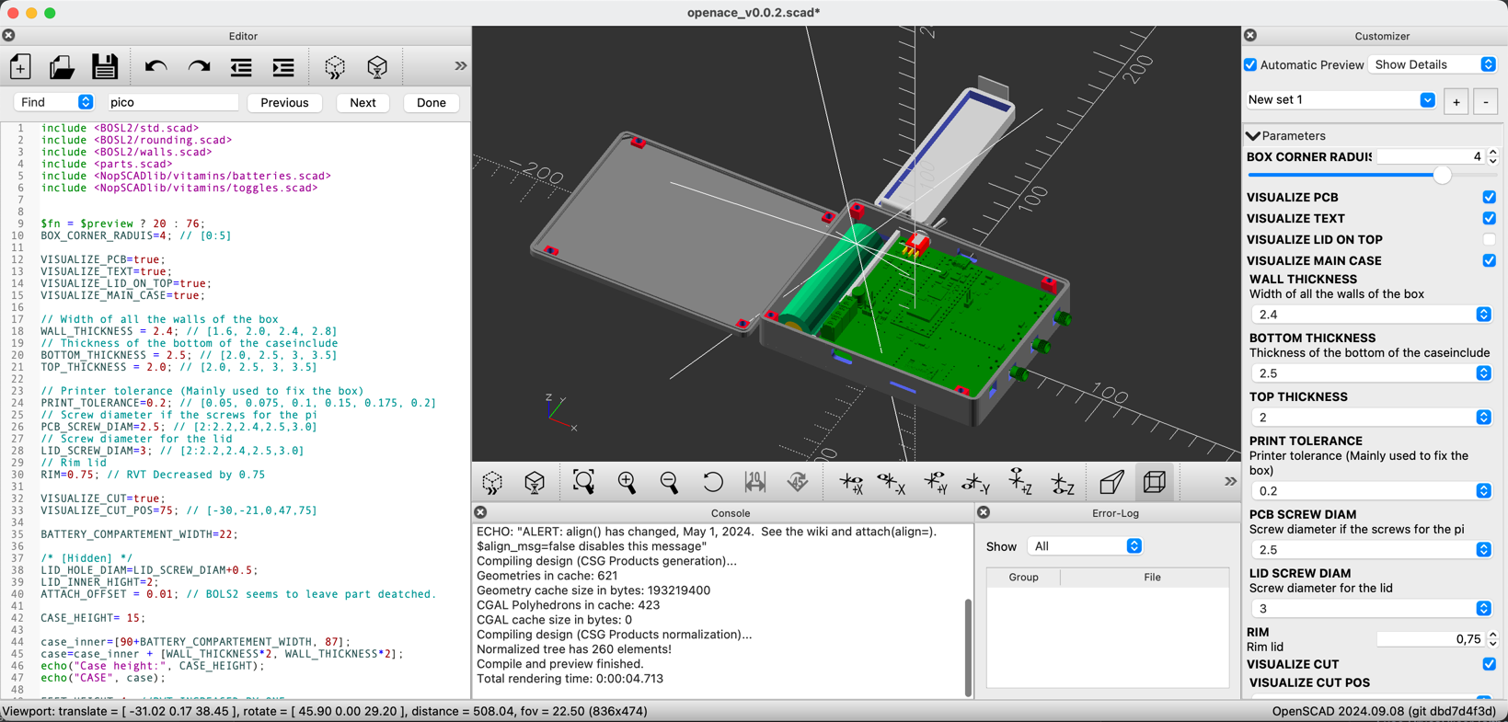
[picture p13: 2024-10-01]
doc/img/openscad.png

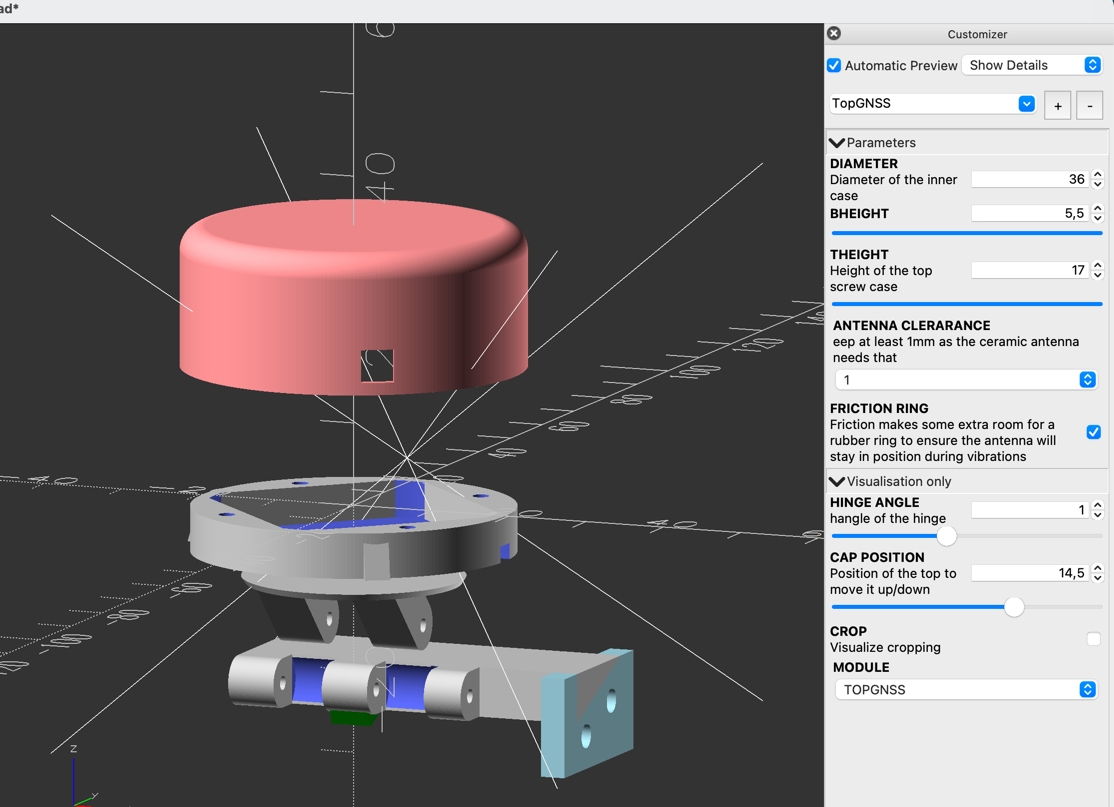
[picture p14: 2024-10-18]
doc/img/gps-antenna-holder.png

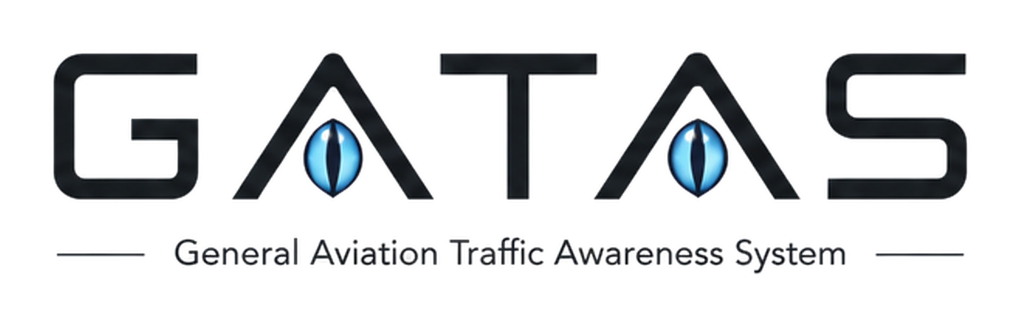
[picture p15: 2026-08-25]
doc/media/gatas-light-tagline.png

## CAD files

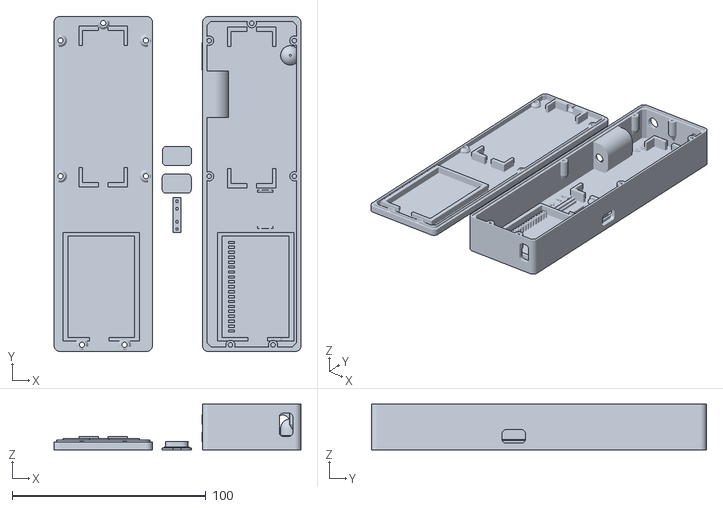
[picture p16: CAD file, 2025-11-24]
enclosure/gatas_Pulse.stl
127.4 x 172.9 x 23.7

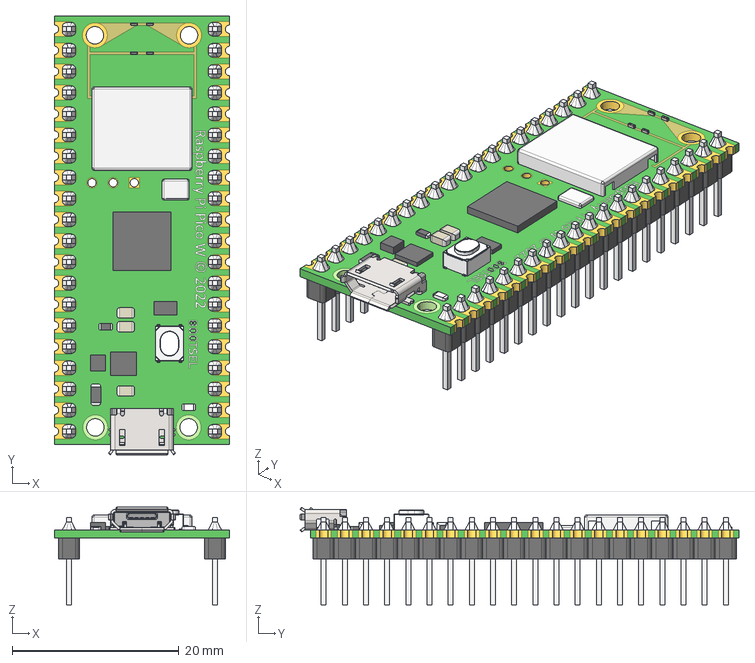
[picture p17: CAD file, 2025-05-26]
enclosure/raspberry-pi-pico-w-rp2040/RaspberryPi-PicoW-WithPins.step
21.0 x 52.7 x 11.7 mm

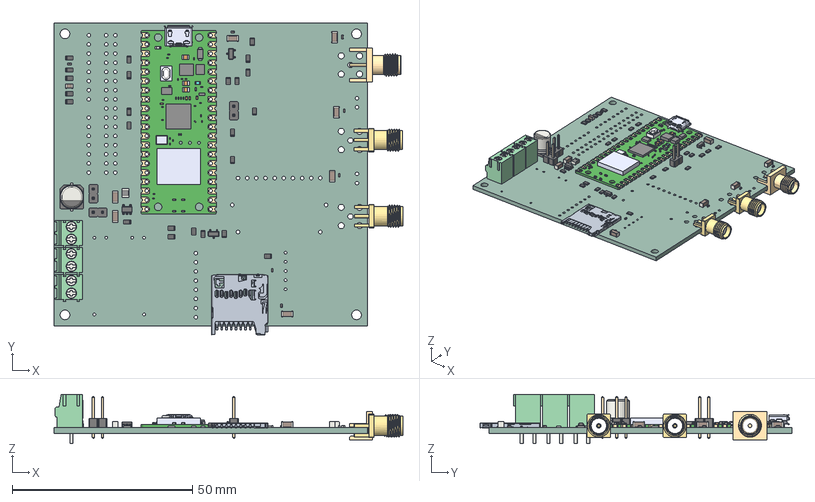
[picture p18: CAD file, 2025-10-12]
OpenACE V0.0.2/openace.step
96.8 x 86.6 x 13.7 mm
R_0805_2012Metric x 24
C_0402_1005Metric x 7
C_1206_3216Metric x 7
TerminalBlock_Phoenix_PT_15_2_35_H_1x02_P350mm_Horizontal x 3
L_1008_2520Metric
PinHeader_1x02_P254mm_Vertical x 3
SOT_23 x 2
SMA_female_edge_6_5x6_5 x 2
SOT_23_5
C_0805_2012Metric
SC0918
CP_Elec_63x77
_autosave-OpenACE V0.0.2_PCB

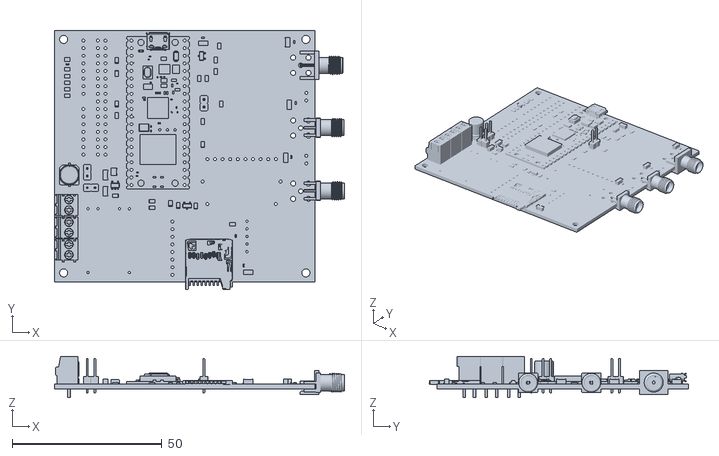
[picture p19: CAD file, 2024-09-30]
enclosure/ImageToStl.com_openace.stl
96.8 x 86.6 x 13.7

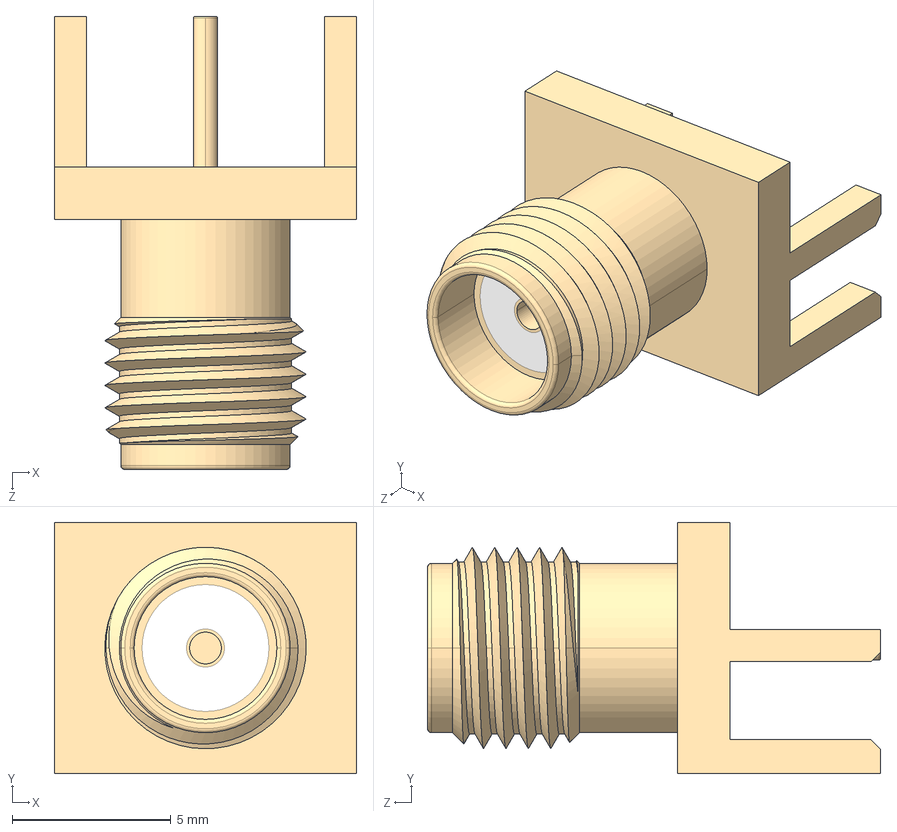
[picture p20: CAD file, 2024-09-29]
OpenACE V0.0.2/2985-6038.STEP
9.53 x 7.92 x 14.3 mm

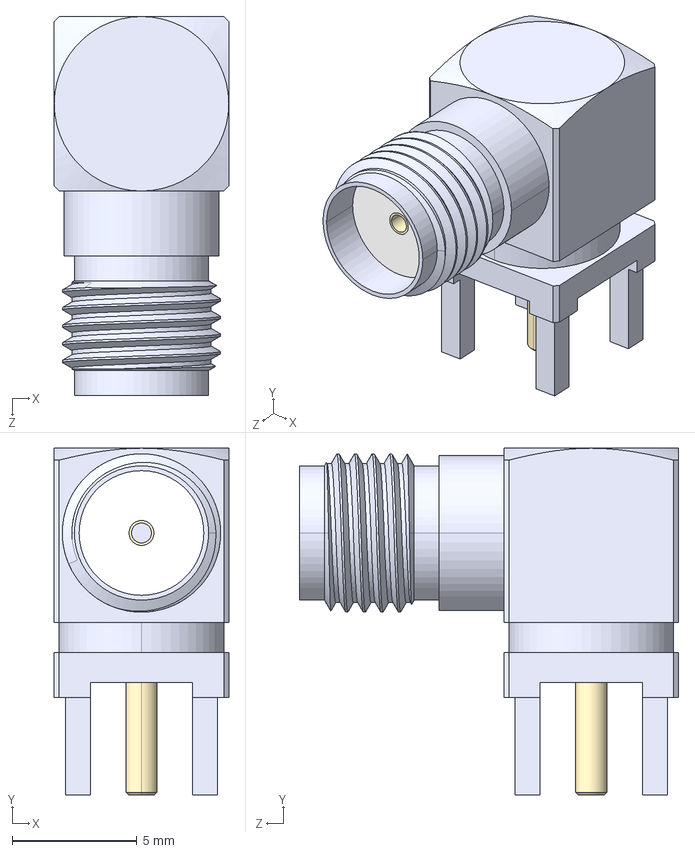
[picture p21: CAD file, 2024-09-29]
OpenACE V0.0.2/CONSMA002--3DModel-STEP-1.STEP
7.00 x 13.9 x 15.2 mm

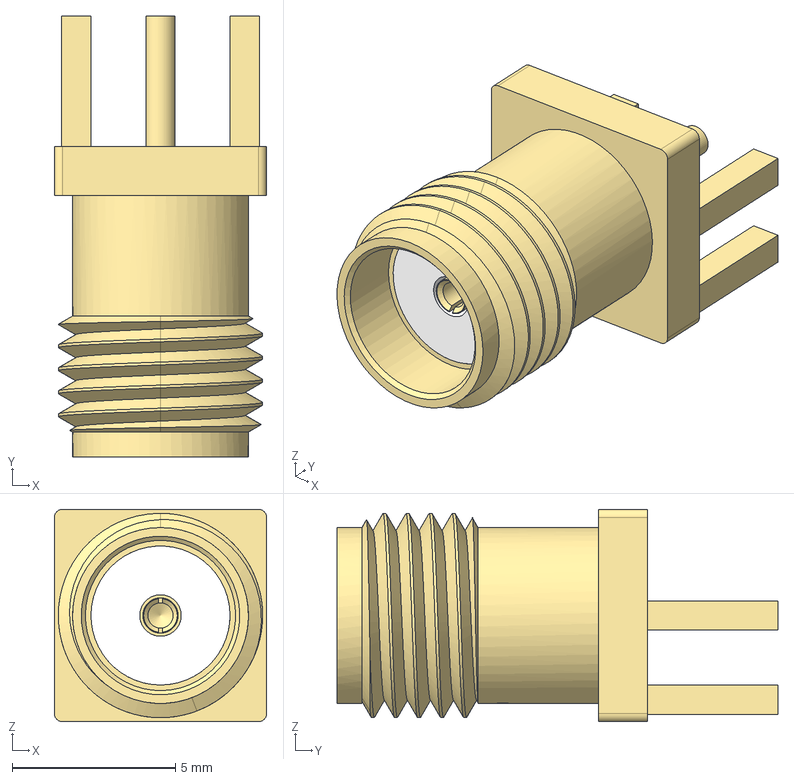
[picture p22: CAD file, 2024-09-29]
OpenACE V0.0.2/SMA_female_edge_6.5x6.5.step
6.50 x 13.5 x 6.50 mm
Dielectric
Pin

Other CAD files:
enclosure/868Mhz-antenna-array.scad
enclosure/gatas_Pulse.scad
enclosure/gatas_v0.0.2.scad
enclosure/gps-antenna-holder.scad
enclosure/openace_v0.0.2.scad
enclosure/parts.scad
enclosure/pcbSupport.scad
enclosure/raspberry-pi-pico-w-rp2040/RaspberryPi-PicoW-WithPins.stl

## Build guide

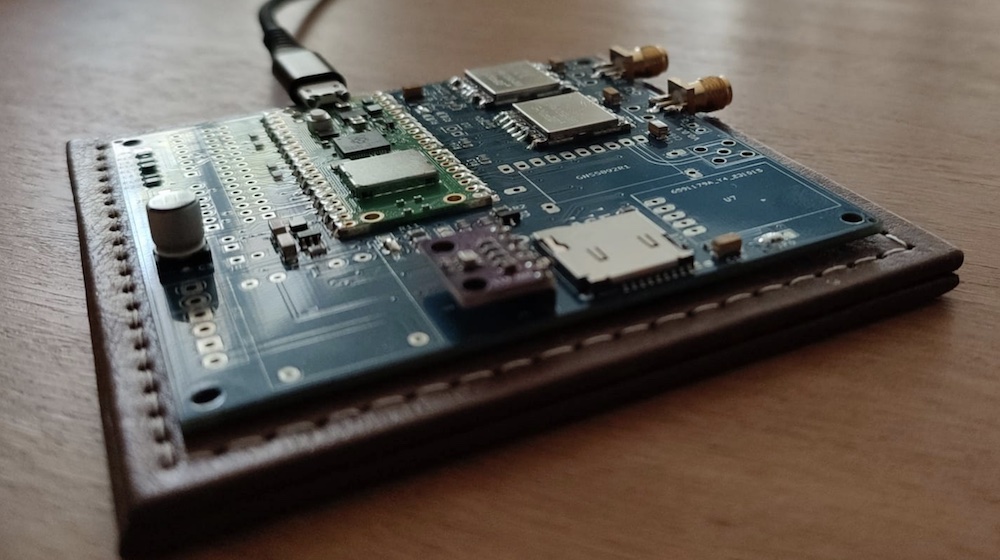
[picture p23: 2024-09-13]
doc/img/solderedpcb.jpg

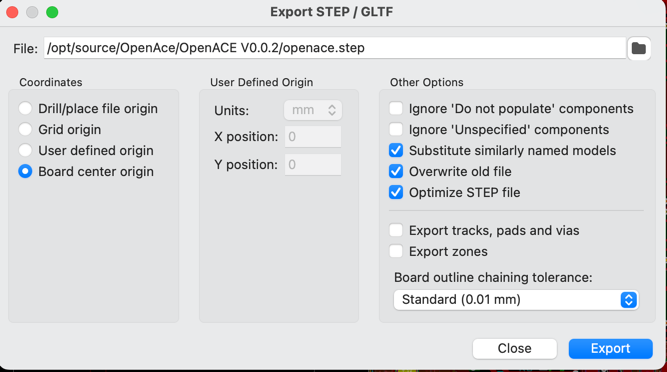
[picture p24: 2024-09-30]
doc/img/kicad-step-stl.png

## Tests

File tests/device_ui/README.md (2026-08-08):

# OpenAce device UI tests

These tests drive the web interface of a physical OpenAce device and verify every
write through its HTTP API.

## Install

```bash
cd tests/device_ui
python3 -m venv .venv
.venv/bin/pip install -e .
.venv/bin/playwright install chromium
```

## Run

Reversible UI and API tests:

```bash
OPENACE_DEVICE_URL=http://192.168.178.227 .venv/bin/pytest
```

Run one area:

```bash
OPENACE_DEVICE_URL=http://192.168.178.227 .venv/bin/pytest tests/test_gatas_connect.py
OPENACE_DEVICE_URL=http://192.168.178.227 .venv/bin/pytest tests/test_foreflight_discovery.py
OPENACE_DEVICE_URL=http://192.168.178.227 .venv/bin/pytest tests/test_flash_persistence.py
```

Validate direct radio traffic with a second transmitting GATAS:

```bash
OPENACE_DEVICE_URL=http://192.168.178.227 .venv/bin/pytest \
  --run-radio-traffic tests/test_aircraft_tracker_radio.py
```

Use `--headed` to watch the browser. Playwright traces and screenshots are
retained for failures under `test-results/`.

The suite creates unique temporary aircraft and removes them afterward.
The ForeFlight discovery test listens on an unused local UDP port, verifies the
device does not send to it before discovery, advertises it to the device, and
then requires several GDL90 packets including a heartbeat.
The flash persistence test temporarily changes the active aircraft category,
calls `SaveBr`, and uses the `GATAS_DEBUG`-only `CompareBr` endpoint to verify
the flash contents immediately. It restores and saves the original aircraft
record before completing; no device restart is required.

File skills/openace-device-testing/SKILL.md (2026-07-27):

---
name: openace-device-testing
description: Test a physical OpenAce device through its HTTP API, including reading and modifying aircraft or module configuration, saving volatile configuration to flash, erasing saved flash configuration, reboot persistence checks, regression testing, and reproducing user-reported device issues. Use for hardware-in-the-loop, integration, persistence, factory-default, configuration, or device regression testing of OpenAce firmware.
---

# OpenAce Device Testing

Test configuration changes safely and leave an evidence trail that another run can reproduce.

## Establish the test target

1. Work from the OpenAce repository and obey its `AGENTS.md`.
2. Prefix every shell command with `rtk`.
3. Obtain the device base URL from the user or existing test context. Never guess a device IP.
4. Use the literal, user-confirmed device URL in commands. If automation needs a variable, use a task-specific name such as `OPENACE_DEVICE`; never use `HOME` or another common system variable.

   ```bash
   rtk curl -fsS http://192.168.4.1/api/Config.json
   ```
5. Record firmware version, board, power arrangement, network path, test time, and the exact starting configuration relevant to the test.
6. Confirm the target is a disposable test device before any flash erase. Treat `EraseBr`, restart, USB boot, radio transmission changes, Wi-Fi changes, and hardware pin changes as important actions.

## Understand configuration state

OpenAce has three configuration sources:

- `Ram`: the current volatile configuration.
- `Flash`: the persisted configuration loaded on boot.
- `Default`: the firmware-embedded defaults.

Read the current source and persistent-store size:

```bash
rtk curl -fsS http://DEVICE/api/Config.json
```

Configuration writes first update RAM and set `config._dirty` to `true`. They are not proven persistent until `SaveBr` succeeds and a reboot loads the same values.

Successful writes return `/ok.json`. Invalid, incomplete, oversized, or rejected
writes return HTTP 400 with `/error.json`. Always perform a GET verification as
well, because transport success does not prove persistence or runtime behavior.

## Snapshot before mutation

Read and save every path that the test will modify. Do not claim a complete backup unless every required top-level path was captured; `/api/Config.json` contains metadata, not the entire configuration document.

Common paths:

```bash
rtk curl -fsS http://DEVICE/api/Config/config.json
rtk curl -fsS http://DEVICE/api/Config/hardware.json
rtk curl -fsS http://DEVICE/api/Config/modules.json
rtk curl -fsS http://DEVICE/api/Config/aircraft.json
rtk curl -fsS http://DEVICE/api/Config/MODULE_NAME.json
```

Store snapshots and test evidence outside source directories containing firmware code. Redact Wi-Fi passwords, service PINs, and other secrets before placing evidence in reports or commits.

Prefer a reversible probe value and change one variable at a time. Avoid connectivity, pin-map, transmitter, and active-aircraft changes unless the test specifically requires them.

## Modify configuration

POST valid JSON to a configuration path. A top-level module or configuration object is replaced/updated through the same path scheme.

Modify a module:

```bash
rtk curl -fsS -X POST -H 'Content-Type: application/json' \
  --data '{"filterAbove":1600,"filterBelow":1500}' \
  http://DEVICE/api/Config/ADSBDecoder.json
rtk curl -fsS http://DEVICE/api/Config/ADSBDecoder.json
```

Modify general configuration:

```bash
rtk curl -fsS -X POST -H 'Content-Type: application/json' \
  --data '{"pilotname":"TEST","aircraftId":"XX-XXX"}' \
  http://DEVICE/api/Config/config.json
rtk curl -fsS http://DEVICE/api/Config/config.json
```

Add or update aircraft data using the callsign as the path:

```bash
rtk curl -fsS -X POST -H 'Content-Type: application/json' \
  --data '{"callSign":"TEST-1","address":11259375,"addressType":"ADSL","category":"Light","privacy":0,"noTrack":0,"groundStation":0,"protocols":[]}' \
  http://DEVICE/api/Config/aircraft/TEST-1.json
rtk curl -fsS http://DEVICE/api/Config/aircraft/TEST-1.json
```

Delete aircraft data through the POST tunnel required by the embedded web server:

```bash
rtk curl -fsS -X POST -H 'X-Method: DELETE' --data '{}' \
  http://DEVICE/api/Config/aircraft/TEST-1.json
rtk curl -fsS http://DEVICE/api/Config/aircraft.json
```

For any module, first GET `/api/Config/MODULE_NAME.json`, modify only fields relevant to the case, POST valid JSON, then GET the same path. Use names and schemas from the running device or `src/pico/gatas_default_config.json`; do not invent fields.

## Save RAM configuration to flash

1. Verify the intended RAM value and `config._dirty`.
2. Save with a non-empty JSON body:

   ```bash
   rtk curl -fsS -X POST -H 'Content-Type: application/json' --data '{}' \
     http://DEVICE/api/Config/SaveBr.json
   ```

3. GET `/api/Config/config.json` and `/api/Config.json`. Expect `_dirty` to be false and a nonzero persistent-store size.
4. Reboot only when temporary network loss is acceptable:

   ```bash
   rtk curl -fsS -X POST -H 'Content-Type: application/json' --data '{}' \
     http://DEVICE/api/Config/Restart.json
   ```

5. Wait for the device to return without using a blocking wait longer than 60 seconds. Reconnect and GET the tested path.
6. Pass persistence only when the exact value survives reboot and `/api/Config.json` reports `Flash` (or the expected source for the tested boot sequence).

## Erase saved flash configuration

Perform this only when the user has authorized destructive testing on the identified test device. Erase removes volatile and persistent configuration stores. The in-memory JSON may remain observable until reboot, so an immediate GET is not proof of either success or failure.

```bash
rtk curl -fsS -X POST -H 'Content-Type: application/json' --data '{}' \
  http://DEVICE/api/Config/EraseBr.json
rtk curl -fsS -X POST -H 'Content-Type: application/json' --data '{}' \
  http://DEVICE/api/Config/Restart.json
```

After reconnection:

1. GET `/api/Config.json`; expect `configuration` to be `Default` and `pStoreSize` to be zero.
2. GET the tested configuration paths and compare them with `src/pico/gatas_default_config.json` for the firmware under test.
3. Confirm identity separately: `EraseBr` erases the configuration stores used here but does not imply that the binary identity store or firmware image was erased.
4. Restore required test configuration explicitly, verify it in RAM, save to flash, reboot, and verify again.

## Run a regression case

Prefer the deterministic Playwright suite in `tests/device_ui/` when the
requested coverage already exists there. Install it in an isolated environment:

```bash
rtk python3 -m venv tests/device_ui/.venv
rtk tests/device_ui/.venv/bin/pip install -e tests/device_ui
rtk tests/device_ui/.venv/bin/playwright install chromium
```

Run reversible UI/API tests:

```bash
rtk tests/device_ui/.venv/bin/pytest tests/device_ui \
  --device-url http://DEVICE
```

Add `--headed` for visible browser execution. Add `--run-persistence` only when
save/restart testing is authorized. Never add `--run-destructive` unless the
identified device is disposable and the user explicitly authorized erasing
stores or entering firmware-update mode.

The suite must:

- use the UI for the action under test and the API for post-action assertions;
- create unique temporary aircraft rather than repurposing operational entries;
- preserve the complete record when varying one field;
- retain Playwright traces and screenshots on failure;
- restore the original selected aircraft and remove temporary records;
- verify cleanup through GET requests.

When adding coverage, keep selectors and workflows in `pages/`, assertions and
parameter matrices in `tests/`, and device transport behavior in
`pages/api_client.py`.

For a manual case not yet represented in the suite, use this sequence:

1. Translate the report into one observable claim.
2. Record prerequisites and the smallest exact reproduction steps.
3. Capture the baseline GET responses.
4. Change one input and verify the RAM result.
5. If persistence is implicated, save, reboot, and verify.
6. If defaults or corruption recovery are implicated, use an authorized erase/reboot and verify.
7. Repeat enough times to distinguish deterministic failures from timing or connectivity issues.
8. Restore the starting state, unless the agreed test ends at factory defaults.
9. Run the relevant desktop regression tests when code changes are involved:

   ```bash
   rtk run sh src/lib/config/config_tests/urun.sh
   ```

Keep desktop tests and physical-device observations separate in the result.

## Report results

Report:

- device, board, firmware/build identifier, and timestamp;
- starting configuration source and relevant snapshot;
- exact requests or UI actions, with secrets redacted;
- expected and actual results;
- response bodies and post-action GET verification;
- whether the behavior occurred before save, after save, after reboot, or after erase;
- reproduction count;
- restoration status;
- verdict: `PASS`, `FAIL`, `INCONCLUSIVE`, or `BLOCKED`;
- suspected subsystem and the next narrow test.

Never mark a test passed solely because a POST returned HTTP success. Never erase, restart, enter USB boot, or alter a safety-relevant transmitter setting on an unidentified or operational device.

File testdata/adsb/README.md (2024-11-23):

## ADSB Test Server

This small utility reads back an adsb.txt file and tries tp spit it out at the same speed it received the data on.

How to run:

```bash
rvt@xxxxx adsb % npm install

added 2 packages, and audited 3 packages in 923ms

found 0 vulnerabilities
```

Then run:

```bash
rvt@xxxxx adsb % node server.js ../adsb.txt 30002
Server listening on port 30002
```

It will now read the text file `adsb.txt` in the above directory and open port 30002.
Then simply tell OpenACE to connect to this computer andport from the Dump1090Client module.

The Dump1090 Client module will use the configuration without rebooting after changing.

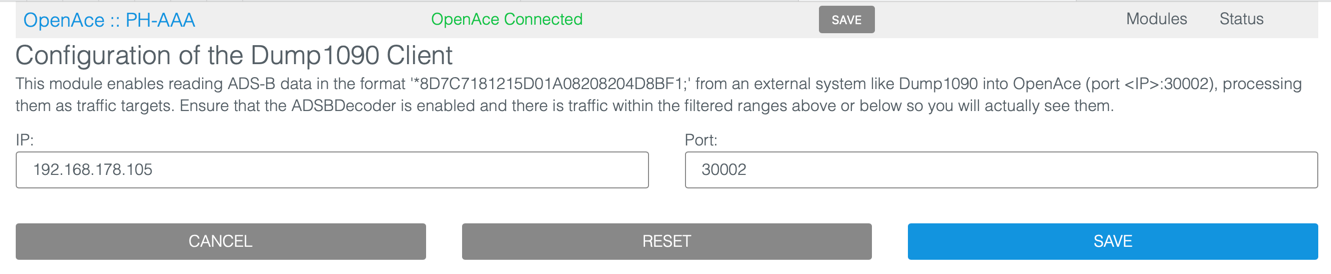
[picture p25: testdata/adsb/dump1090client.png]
Dump1090CLient module


When everything works and the connection is made, the received counter should steadly increase:

Note: If you have dump1090 running you could also connect to this. The data is exactly the same.

dump1090monitor

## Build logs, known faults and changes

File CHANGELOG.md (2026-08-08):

# Changelog

All notable changes to this project will be documented in this file.

The format is based on [Keep a Changelog](https://keepachangelog.com/en/1.0.0/),
and this project adheres to [Semantic Versioning](https://semver.org/spec/v2.0.0.html).

## [Unreleased]

### Added

-

### Changed

-

### Deprecated

-

### Removed

-

### Fixed

-

### Security

-

## [v3.2.2] - 2026-08-08

### Added

-

### Changed

- Clarified in the GDL over UDP module overview and configuration panel that ForeFlight clients and their advertised GDL90 ports are discovered automatically.
- Extended the ForeFlight simulator to listen on its advertised GDL90 UDP port and count received packets.
- Added a device integration test that verifies GDL90 UDP traffic starts only after ForeFlight advertises its listening port and includes heartbeat messages.

### Deprecated

-

### Removed

-

### Fixed

-

### Security

-

## [v3.2.1] - 2026-08-06

### Added

-

### Changed

-

### Deprecated

-

### Removed

-

### Fixed

- Fixed the aircraft selector showing the last configured aircraft after a webpage reload instead of the active aircraft saved in the device configuration.

### Security

## [v3.2.0] - 2026-07-26

### Added

- Added MLAT as a recognized aircraft data source with full and compact display names.
- Added a combined UDP and Bluetooth output mode for GATAS Connect.

### Changed

- Redesigned the SystemGUI with Pico CSS, responsive navigation, consistent forms and dialogs, clearer device status, and improved module monitoring layouts.
- SystemGUI navigation now follows URL hashes so pages can be linked directly and restored after reload.
- SystemGUI now enables saving modified RAM configuration to flash only when no aircraft or module configuration editor is open.
- Combined GATAS Connect output now prefers UDP traffic while UDP responses are active and automatically restores Bluetooth requests when UDP becomes silent.
- Improved RP2040 startup memory allocation to reduce module load failures.

### Deprecated

-

### Removed

-

### Fixed

- Fixed RP2350 Bluetooth flash storage overlapping saved configuration, so settings survive restarts and firmware updates.
- Fixed configuration updates so invalid or incomplete requests are rejected without partially changing settings, including creation of new aircraft entries.
- Fixed fragmented and larger web configuration requests being truncated or partially applied.
- Fixed GATAS Connect decoding of larger aircraft frames and variable-length callsigns, preventing corrupted traffic and incorrect data-source values.
- Fixed radio transmit scheduling when all configured protocol timings are active.
- Improved radio and aircraft-tracking queue handling for reliable processing across tasks.
- Fixed SX1262 receive metadata being associated with the wrong tuned protocol and corrected transmit-power limiting.
- Initialized GPS satellite-in-view counters, radio identifiers, and AirConnect client state before use.
- Aircraft tracking now preserves fresh positions received directly over radio when matching ADS-B or MLAT updates arrive, until the radio-priority timeout expires.

### Security

-

## [v3.1.0] - 2026-07-13

### Added

- Experimental aircraft path prediction in `AircraftTracker`, using recent position, speed, heading, vertical speed, and turn-rate history to extrapolate short gaps in tracked traffic.
- Desktop test coverage for aircraft path prediction and updated antenna-radiation bearing behavior.
- Squawk code tracking on `AircraftPositionInfo`, including ADS-B squawk capture and an `AircraftTracker` option to show known squawk codes instead of callsigns.

### Changed

- Added an `AircraftTracker` configuration and web UI option to enable or disable path prediction.
- `AircraftTracker` now keeps lightweight predictor state for nearby traffic and can forward extrapolated positions during scheduled client updates.
- Normalized several tracker/core numeric types and math helpers, including 32-bit ellipsoid heights and float-specific angle/CPR calculations.
- `AIRCRAFT_POSITION_TYPE_V2` binary messages now include a signed 16-bit squawk field after aircraft category; `-1` means unknown.

### Deprecated

-

### Removed

-

### Fixed

- Fixed antenna radiation pattern bearing calculation so radial placement is based on ownship track and target position, not the target aircraft track.
- Fixed protocol/config bounds handling for tracked-aircraft distance and transmitted altitude values in FLARM, FANET, and OGN paths.
- OGN, FLARM, and binary V2 aircraft positions with unavailable or out-of-window minute-relative timestamps are now logged and discarded instead of being treated as current.
- `AircraftTracker` now rejects out-of-order position updates before they can replace newer coordinates or desynchronize predictor history.
- Restored timer-driven `AircraftTracker` scheduling so continuous position notifications cannot suppress heartbeat and predicted-position output.
- Added timer-driven SX1262 TX timeout recovery so a missing `DIO1_TX_DONE` interrupt cannot leave the radio stuck waiting for another task notification.
- Aircraft already tracked are now removed immediately when a current position places them outside the adaptive tracking radius.
- Aircraft path prediction now prefers protocol-provided horizontal turn rates, with heading-history derivation retained as a fallback.

### Security

-

## [v3.0.1] - 2026-06-13

### Added

- Added support for two named SPI buses devices can communicate with

### Changed

-

### Deprecated

-

### Removed

-

### Fixed

- New way of setting processor speed did not always work, back to 200Mhz

### Security

-

## [v3.0.0] - 2026-06-11

### Added

- Initial GATAS Companion support with a new `GatasConnect` core module and a separate `GatasConnectUDP` transport module.
- Bluetooth transport for GATAS Connect, including dedicated NMEA and binary GATT characteristics for companion-device integration.
- Optional GDL90-over-Bluetooth bridge using COBS-framed payloads for companion applications.
- Debug-only FreeRTOS queue registry entries for mutexes, to improve visibility in `GATAS_DEBUG` builds.
- Frontend unit-test support for `SystemGUI` via `npm test`.
- Option to prefix aircraft callsigns with a two-letter datasource code.
- Remote switching between Wi-Fi access-point and client modes from companion/mobile applications.

### Changed

- Split GATAS Connect so COBS framing and request generation live in `GatasConnect`, while UDP transport is handled by `GatasConnectUDP`.
- Extended the web UI to configure GATAS Connect output, pin code, and GDL90 bridge settings, plus a separate UDP server configuration module.
- Improved module monitoring to render structured object and array values more clearly.
- Updated the bundled device database.
- Reworked `vDiagnosticsTask()` so task runtime statistics are reported from `uxTaskGetSystemState()` directly, with clearer boot-time and recent-window CPU metrics for SMP builds.
- Refactored `CoreUtils` from a static utility class into a namespace, while keeping mutable internal state private to the implementation file.
- Bluetooth advertising now splits the local name between the primary advertisement and scan response payloads, improving visibility of longer device names while keeping the custom service UUID advertised.
- Refined `GatasConnect` web configuration so the GDL90 bridge option is only shown for Bluetooth output modes, and documented frontend test usage.
- Optimised SX1262 protocol reconfiguration by tracking the currently programmed protocol and modulation, avoiding unnecessary full radio reconfiguration while keeping explicit standby mode selection.
- Improved aircraft tracker performance by about 20%.
- Renamed `OGN1` to `OGN` in UI and configuration-facing labels.

### Deprecated

-

### Removed

-

### Fixed

- Fixed misleading task runtime reporting in diagnostics, where formatted runtime text could be mismatched against sorted task names.
- Fixed diagnostics labels and notes so CPU usage on the dual-core RP2040 SMP build is presented more honestly.
- Fixed aircraft tracker antenna polar output so it only reports radio-backed data sources, avoiding invalid transport-category entries in the UI.
- Fixed SX1262 LoRa RX bandwidth mapping for 500 kHz channels and capped TX power correctly at the radio maximum.
- Fixed radio receive statistics for FLARM, OGN so polar/range tracking only counts valid in-range packets.
- Fixed Bluetooth NMEA notifications so buffered data is only discarded after a successful notify call.

### Security

-

## [v2.1.1] - 2026-04-30

### Added

-

### Changed

-

### Deprecated

-

### Removed

-

### Fixed

- Better rendering of RadioTUnerTX and Protocol Timing in the UI
- Moved the 'action' buttons to a seperate page in the UI

### Security

-

## [v2.1.0] - 2026-04-28

### Added

-

### Changed

- FLARM packets will now be corrected for bit flips when possible to improve reception on larger distances

### Deprecated

-

### Removed

-

### Fixed

- AntennaRadionPattern was alligned to north instead of track of aircraft. Only issue in the web interface

### Security

-

## [v2.0.1] - 2026-04-23

### Added

- Prefer radio-derived positions over ADS-B when an aircraft is received from multiple data sources. Only switch to ADS-B if the radio position is older than
  4,000,000 µs (4 seconds). This avoids sudden position jumps, as ADS-B data is typically delayed. And we trust radio positions more.

### Changed

-

### Deprecated

-

### Removed

-

### Fixed

-

### Security

-

## [v2.0.0] - 2026-04-13

### Added

- ADSL Traffic Uplink on O-Band for both reception and transmission (in ground station mode)
- Groundstation mode that can show a static object at any height.
- Send Traffic over ADSL using uplinkTraffic message
- Low power mode during development
- Allow for per protocol RX or TX, or RX and TX selection
- Show in aircraft tracker the aircraft that it is tracking
- Adaptive protocol prioritisation. This will allocate more listening slots for protocols that is actually received to increase pings per aircraft

### Changed

- When GATAS is Stationary, reduce TX times for positional data to average of 5..6 seconds
- Use etl::delegate instead of etl::function
- Stopped storing a 'GATAS::*Msg' in local objects, always copy the contents as a rule
- Update list of possible Aircraft types in UI
- Update DDB
- Better represent RX Schedule with multiple protocols
- Use xTaskNotifyWait instead of ulTaskNotifyTake
- Removed the mutexes from the MessageRouter

### Deprecated

-

### Removed

-

### Fixed

- Regression on FANET TX
- Possible zero or negative values in FreeRTOS delays
- Fixed Incorrectly handle of device error on transceiver

### Security

-

## [v1.2.0] - 2026-03-12

### Added

- Show polar diagrams one ranges per each protcol on AircraftTracker

### Changed

- Update on the web interface where dimensions are shown instead of raw numbers
- Update on the aircraft database

### Fixed

- GDL90 Bug where negative lat/log where not resolved correctly on output

## [v1.1.0] - 2026-03-02

- Initial release of GATAS

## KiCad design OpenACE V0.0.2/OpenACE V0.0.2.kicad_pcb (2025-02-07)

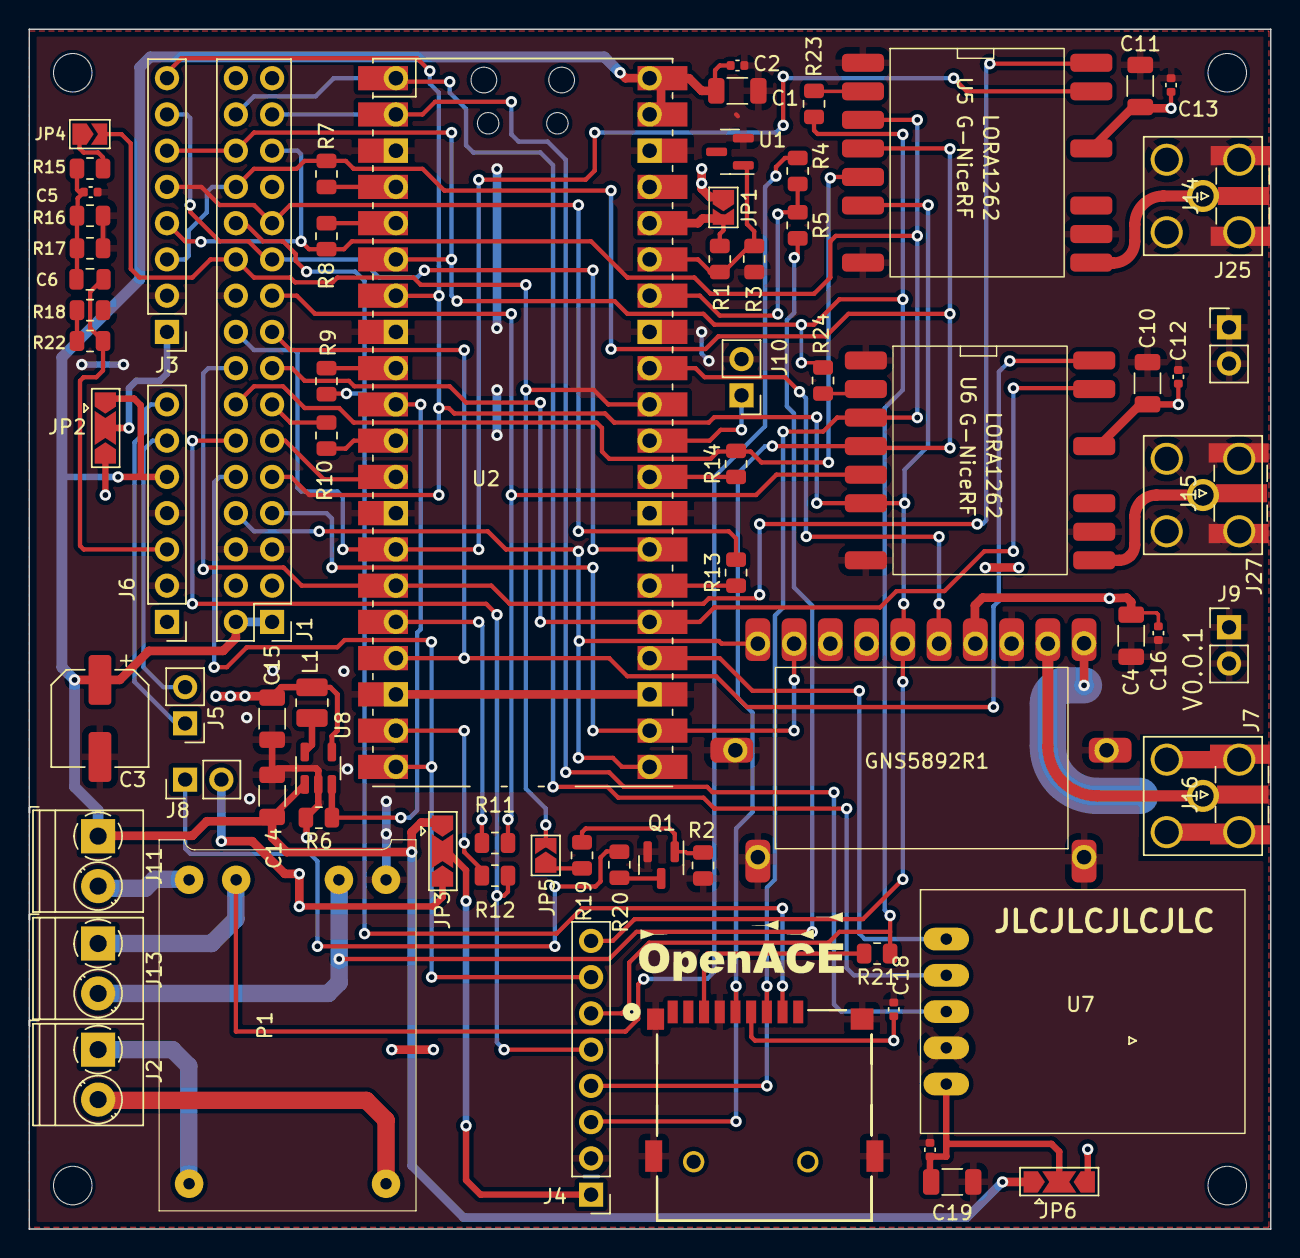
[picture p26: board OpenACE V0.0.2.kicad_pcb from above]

Board: 2 copper layers, 87.0 x 84.1 mm, 79 parts (0 on the bottom side), 66 nets.

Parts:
C1, C4, C10, C11, C14, C15, C19: 10uF; C_1206_3216Metric
C2, C5, C12, C13, C16, C18, C20: 100nF; C_0402_1005Metric
C3: 220uF; CP_Elec_6.3x7.7
C6: 22uF; C_0805_2012Metric
GNS5892R1: GNS Module; GNS5892R1
H1, H2, H3, H4: MountingHole; MountingHole_2.7mm
J1: Conn_02x16_Odd_Even; PinHeader_2x16_P2.54mm_Vertical
J2: Power 5V; TerminalBlock_Phoenix_PT-1,5-2-3.5-H_1x02_P3.50mm_Horizontal
J3, J4: Conn_01x08_Pin; PinHeader_1x08_P2.54mm_Vertical
J5: Speaker; PinHeader_1x02_P2.54mm_Vertical
J6: Conn_01x07_Pin; PinHeader_1x07_P2.54mm_Vertical
J7, J25, J27: Conn_Coaxial; SMA_Amphenol_132203-12_Horizontal
J8, J9, J12: LED; PinHeader_1x02_P2.54mm_Vertical
J10: ~{RUN}; PinHeader_1x02_P2.54mm_Vertical
J11: Power Switch; TerminalBlock_Phoenix_PT-1,5-2-3.5-H_1x02_P3.50mm_Horizontal
J13: Battery; TerminalBlock_Phoenix_PT-1,5-2-3.5-H_1x02_P3.50mm_Horizontal
J14, J15, J16: Conn_Coaxial; SMA_Samtec_SMA-J-P-X-ST-EM1_EdgeMount
JP1: PICO Power; SolderJumper-2_P1.3mm_Open_TrianglePad1.0x1.5mm
JP2, JP3, JP6: SolderJumper_3_Open; SolderJumper-3_P2.0mm_Open_TrianglePad1.0x1.5mm
JP4: Speaker; SolderJumper-2_P1.3mm_Open_TrianglePad1.0x1.5mm
JP5: LED; SolderJumper-2_P1.3mm_Open_TrianglePad1.0x1.5mm
L1: 2.2uH; L_1008_2520Metric
P1: Power Module / Battery Charger; TP4056-charger-module
Q1: S8050; SOT-23
R1, R18: 750; R_0805_2012Metric
R2, R3, R6: 10K; R_0805_2012Metric
R4: 470K; R_0805_2012Metric
R5: 680K; R_0805_2012Metric
R7, R8, R9, R10, R11, R12, R13, R14, R21, R23, R24: 33; R_0805_2012Metric
R15, R16, R17, R20: 220; R_0805_2012Metric
R19, R22: 1K; R_0805_2012Metric
U1: LM4040DBZ-3; SOT-23
U2: SC0918; MODULE_SC0918
U5, U6: G-NiceRF / LORA1262; lora1262
U7: GPS Module M8N; gps_module_1
U8: LM3671MF-3.3; SOT-23-5
U9: MicroSD card (TF card); CONN9_0185-02_GSW

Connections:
+3V3: JP1.2 (B), R1.1, U2.36 (3V3_OUT)
+5V: C1.1, C2.1, C3.1, C14.1, J1.1, J1.2, J6.5, J11.1, JP2.1 (A), JP3.1 (A), JP6.1 (A), U2.39 (VSYS), U2.40 (VBUS), U8.1 (VIN)
/ADC_VRef: R1.2, R3.1, U1.1 (K), U2.35 (ADC_VREF)
/PWR+: J2.1, P1.5 (P+)
/PWR-: J2.2, P1.6 (P-)
/adsb_frame: GNS5892R1.5 (F_ind), U2.32 (GP27)
/bat+: J13.1, P1.1 (B+), R4.1
/bat-: J13.2, P1.2 (B-), R5.2
/battery_ref: R4.2, R5.1, U2.34 (GP28)
/gpio11_dio1: J1.18, U2.14 (GP10), U5.15 (DIO1)
/gpio12_busy1: J1.16, U2.15 (GP11), U5.16 (BUSY)
/gpio13_cs1: J1.14, R14.2, U5.5 (NSS)
/gpio21_cs3: J1.12, J4.5, R12.2
/gpio22_busy3: J1.10, J4.7, U2.20 (GP15)
/gpio31_tx4_cs2: J1.19, R11.1, U6.5 (NSS)
/gpio32_rx4_busy2: J1.17, U2.17 (GP13), U6.16 (BUSY)
/gpio33_pps_dio2: J1.15, U2.25 (GP19), U6.15 (DIO1)
/gpio41_tx5_cs4: J1.23, J3.5, R13.2
/gpio42_rx5_busy4: J1.21, J3.7, U2.27 (GP21)
/gpio51_tx3_cs5: J1.13, R10.1
/gpio52_rx3_busy5: J1.11, U2.12 (GP9)
/gpio61: J1.22, JP4.2 (B), JP5.2 (B), U2.31 (GP26)
/gpio71: R6.1, U2.10 (GP7), U8.3 (EN)
/gps_pps: U2.24 (GP18), U7.5 (PPS)
/mod_rst: GNS5892R1.6 (~Reset), J1.9, J3.8, J4.8, U2.7 (GP5), U5.6 (~RST), U6.6 (~RST)
/rx1: J1.29, U2.2 (GP1), U7.3 (TX)
/rx2: GNS5892R1.9 (Tx), J1.7, U2.22 (GP17)
/sdc_cs: J1.24, R9.1, U9.2 (DAT3/CD)
/spi_clk: J1.26, J3.3, J4.3, R7.1, U5.4 (SCK), U6.4 (SCK), U9.5 (CLK)
/spi_miso: J1.28, J3.6, J4.6, R21.1, R23.1, R24.1, U2.6 (GP4)
/spi_mosi: J1.27, J3.4, J4.4, R8.1, U5.3 (MOSI), U6.3 (MOSI), U9.3 (CMD)
/tx1: J1.30, U2.1 (GP0), U7.4 (RX)
/tx2: GNS5892R1.10 (Rx), J1.8, U2.21 (GP16)
GNDD: C1.2, C2.2, C3.2, C4.2, C5.2, C10.2, C11.2, C12.2, C13.2, C14.2, C15.2, C16.2, C18.2, C19.2, C20.2, GNS5892R1.3 (GND), GNS5892R1.11 (GND), GNS5892R1.12 (GND), GNS5892R1.13 (GND), GNS5892R1.14 (GND), J1.5, J1.6, J1.20, J3.2, J4.2, J6.2, J6.4, J9.1, J9.2, J10.2, J12.1, J12.2, J14.2 (Ext), J15.2 (Ext), J25.2 (Ext), J27.2 (Ext), P1.4 (-), Q1.2 (E), R2.1, R3.2, R6.2, R16.1, R17.1, R18.2, U1.2 (A), U2.3 (GND), U2.8 (GND), U2.13 (GND), U2.18 (GND), U2.23 (GND), U2.28 (GND), U2.33 (AGND), U2.38 (GND), U5.1 (GND), U5.8 (GND), U5.10 (GND), U6.1 (GND), U6.8 (GND), U6.10 (GND), U7.2 (GND), U8.2 (GND), U9.6 (VSS), U9.12 (SHIELD), U9.13 (SHIELD), U9.14 (SHIELD), U9.15 (SHIELD)
unnamed: C5.1, C6.1, R15.1, R16.2, R17.2
unnamed: GNS5892R1.1 (RF_Gnd), J7.2 (Ext), J16.2 (Ext)
unnamed: GNS5892R1.2 (RF_in), J7.1 (In), J16.1 (In)
unnamed: J3.1, JP2.2 (C)
unnamed: J4.1, JP3.2 (C)
unnamed: J5.1, J6.7
unnamed: J5.2, J6.6
unnamed: C6.2, J6.3, R22.2
unnamed: J8.1, R20.1
unnamed: J10.1, U2.30 (~RUN)
unnamed: J11.2, P1.3 (+)
unnamed: J14.1 (In), J25.1 (In), U5.9 (ANT)
unnamed: J15.1 (In), J27.1 (In), U6.9 (ANT)
unnamed: JP4.1 (A), R15.2
unnamed: JP5.1 (A), R19.1
unnamed: C19.1, C20.1, JP6.2 (C), U7.1 (VCC)
unnamed: Q1.1 (B), R2.2, R19.2
unnamed: Q1.3 (C), R20.2
unnamed: R18.1, R22.1
unnamed: R7.2, U2.4 (GP2)
unnamed: R8.2, U2.5 (GP3)
unnamed: R9.2, U2.9 (GP6)
unnamed: R10.2, U2.11 (GP8)
unnamed: R11.2, U2.16 (GP12)
unnamed: R12.1, U2.19 (GP14)
unnamed: R13.1, U2.26 (GP20)
unnamed: R14.1, U2.29 (GP22)
unnamed: R23.2, U5.2 (MISO)
unnamed: R24.2, U6.2 (MISO)
unnamed: L1.1, U8.5 (SW)
unnamed: R21.2, U9.7 (DAT0)
VCC: C4.1, C10.1, C11.1, C12.1, C13.1, C15.1, C16.1, C18.1, GNS5892R1.4 (VDD), J1.3, J1.4, J8.2, JP1.1 (A), JP2.3 (B), JP3.3 (B), JP6.3 (B), L1.2, U5.13 (VCC), U6.13 (VCC), U8.4 (FB), U9.4 (VDD)

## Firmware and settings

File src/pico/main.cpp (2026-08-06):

#include "main.h"
#include "generated/build_time.hpp"
#include "generated/default_config.hpp"

/* System. */
#include <stdio.h>
#include <malloc.h>

/* FreeRTOS. */
#include "FreeRTOS.h"
#include "croutine.h"
#include "task.h"

/* pico */
#include "pico/stdlib.h"
#include "pico/cyw43_arch.h"
#include "pico/btstack_cyw43.h"
#include "pico/cyw43_driver.h"

/* Vendor. */
#include "etl/list.h"
#include "etl/error_handler.h"
#include "etl/exception.h"

/* GaTas. */
#include "ace/serialadsb.hpp"
#include "ace/dump1090client.hpp"

#include "ace/messagerouter.hpp"
#include "ace/constants.hpp"
#include "ace/aircrafttracker.hpp"
#include "ace/basemodule.hpp"
#include "ace/config.hpp"
#include "ace/inmemorystore.hpp"
#include "ace/flashstore.hpp"
#include "ace/ubloxm8n.hpp"
#include "ace/L76B.hpp"
#include "ace/adsbdecoder.hpp"
#include "ace/picortc.hpp"
#include "ace/wifiservice.hpp"
#include "ace/webserver.hpp"
#include "ace/gpsdecoder.hpp"
#include "ace/acespi.hpp"
#include "ace/bmp280.hpp"
#include "ace/sx1262.hpp"
#include "ace/radiotunerrx_v2.hpp"
#include "ace/rxdataframequeue.hpp"
#include "ace/radiotunertx_v2.hpp"
#include "ace/flarm2024.hpp"
#include "ace/ogn1.hpp"
#include "ace/adslace.hpp"
#include "ace/gdl90service.hpp"
#include "ace/gdloverudp.hpp"
#include "ace/dataport.hpp"
#include "ace/airconnect.hpp"
#include "ace/gatasconnect.hpp"
#include "ace/gatasconnectudp.hpp"
#include "ace/bluetooth.hpp"
#include "ace/fanetace.hpp"
#include "ace/idle.hpp"
#include "ace/manchester.hpp"

const char *GATAS_BUILD_TIMESTAMP = BUILD_TIMESTAMP;
const char *GATAS_BUILD_GIT_TAG = BUILD_GIT_TAG;
const uint32_t GATAS_BUILD_TIMESTAMP_EPOCH = BUILD_TIMESTAMP_EPOCH;

void etlcpp_receive_error(const etl::exception &e)
{
    printf("ETLCPP error was %s in file %s at line %d\n", e.what(), e.file_name(), e.line_number());
}

uint32_t getTotalHeap(void)
{
    extern char __StackLimit, __bss_end__;
    return &__StackLimit - &__bss_end__;
}

uint32_t getFreeHeap(void)
{
    auto m = mallinfo();
    return getTotalHeap() - m.uordblks;
}

void registerModules()
{
    BaseModule::registerModule(AceSpi::NAMES[0], true);
    BaseModule::registerModule(AceSpi::NAMES[1], true);
    BaseModule::registerModule(Bmp280::NAME, true);
    // BaseModule::registerModule(Config::NAME, true); // Uncomment if needed
    BaseModule::registerModule(Gdl90Service::NAME, false);
    BaseModule::registerModule(WifiService::NAME, false);
    BaseModule::registerModule(Webserver::NAME, false);
    BaseModule::registerModule(PicoRtc::NAME, false);
    BaseModule::registerModule(Sx1262::NAMES[0], true);
    BaseModule::registerModule(Sx1262::NAMES[1], true);
    BaseModule::registerModule(RadioTunerTx::NAME, false);
    BaseModule::registerModule(RadioTunerRx::NAME, false);
    BaseModule::registerModule(RxDataFrameQueue::NAME, false);
    BaseModule::registerModule(ADSBDecoder::NAME, false);
    BaseModule::registerModule(Flarm2024::NAME, false);
    BaseModule::registerModule(Ogn1::NAME, false);
    BaseModule::registerModule(ADSLAce::NAME, false);
    BaseModule::registerModule(GDLoverUDP::NAME, false);
    BaseModule::registerModule(GpsDecoder::NAME, false);
    BaseModule::registerModule(UbloxM8N::NAME, true);
    BaseModule::registerModule(L76B::NAME, true);
    BaseModule::registerModule(SerialADSB::NAME, true);
    BaseModule::registerModule(Dump1090Client::NAME, false);
    BaseModule::registerModule(AircraftTracker::NAME, false);
    BaseModule::registerModule(DataPort::NAME, false);
    BaseModule::registerModule(AirConnect::NAME, false);
    BaseModule::registerModule(GatasConnect::NAME, false);
    BaseModule::registerModule(GatasConnectUDP::NAME, false);
    BaseModule::registerModule(Bluetooth::NAME, false);
    BaseModule::registerModule(FanetAce::NAME, false);
    BaseModule::registerModule(Idle::NAME, false);

    for (auto a : BaseModule::registeredModules())
    {
        printf("Registered %s\n", a.first.cbegin());
    }
}

GATAS::GlobalPoolConfiguration pool;

void disabled(etl::string_view name, Configuration &config)
{
    // clang-format off
    if (name == Sx1262::NAMES[0]) {
        Sx1262::enterDisabledState(0, config);
    }
    if (name == Sx1262::NAMES[1]) {
        Sx1262::enterDisabledState(1, config);
    }
    // clang-format on
}

BaseModule *loadModule(etl::string_view name, etl::imessage_bus &bus, Configuration &config)
{
    // clang-format off
    if (name == Ogn1::NAME)
        return new Ogn1(bus, config);
    if (name == FanetAce::NAME)
        return new FanetAce(bus, config);
    if (name == ADSLAce::NAME)
        return new ADSLAce(bus, config);
    if (name == Flarm2024::NAME)
        return new Flarm2024(bus, config);
    if (name == AirConnect::NAME)
        return new AirConnect(bus, config);
    if (name == GatasConnect::NAME)
        return new GatasConnect(bus, config);
    if (name == GatasConnectUDP::NAME)
        return new GatasConnectUDP(bus, config);
    if (name == Bluetooth::NAME)
        return new Bluetooth(bus, config);
    if (name == DataPort::NAME)
        return new DataPort(bus, config);
    if (name == AircraftTracker::NAME)
        return new AircraftTracker(bus, config);
    if (name == Dump1090Client::NAME)
        return new Dump1090Client(bus, config);
    if (name == SerialADSB::NAME)
        return new SerialADSB(bus, config);
    if (name == L76B::NAME)
        return new L76B(bus, config);
    if (name == UbloxM8N::NAME)
        return new UbloxM8N(bus, config);
    if (name == GpsDecoder::NAME)
        return new GpsDecoder(bus, config);
    if (name == GDLoverUDP::NAME)
        return new GDLoverUDP(bus, config);
    if (name == ADSBDecoder::NAME)
        return new ADSBDecoder(bus, config);
    if (name == RadioTunerRx::NAME)
        return new RadioTunerRx(bus, config);
    if (name == RadioTunerTx::NAME)
        return new RadioTunerTx(bus, config);
    if (name == RxDataFrameQueue::NAME)
        return new RxDataFrameQueue(bus, config);
    if (name == Sx1262::NAMES[0])
        return new Sx1262(bus, config, 0);
    if (name == Sx1262::NAMES[1])
        return new Sx1262(bus, config, 1);
    if (name == PicoRtc::NAME)
        return new PicoRtc(bus, config);
    if (name == Webserver::NAME)
        return new Webserver(bus, config);
    if (name == WifiService::NAME)
        return new WifiService(bus, config);
    if (name == Gdl90Service::NAME)
        return new Gdl90Service(bus, config);
    if (name == Bmp280::NAME)
        return new Bmp280(bus, config);
    if (name == AceSpi::NAMES[0])
        return new AceSpi(bus, config, 0);
    if (name == AceSpi::NAMES[1])
        return new AceSpi(bus, config, 1);
    if (name == Idle::NAME)
        return new Idle(bus, config);
    // if (name == Config::NAME) return new Config(bus, FlashStore, DEFAULT_GATAS_CONFIG); // Uncomment if needed
    // clang-format on

    return nullptr; // Unknown name
}

constexpr size_t VOL_DATA_SIZE = 4096;
uint8_t __uninitialized_ram(store[VOL_DATA_SIZE]);
static InMemoryStore volatileStore{VOL_DATA_SIZE, store};

// Flash memory map, from low to high addresses:
// RP2040: Application | Binary Store | Permanent Store | Bluetooth (2 sectors)
// RP2350:
//   end - 6 sectors: Bluetooth bank 0
//   end - 5 sectors: Bluetooth bank 1
//   end - 4 sectors: Binary Store
//   end - 3 sectors: Permanent Store (application configuration, unchanged)
//   end - 2 sectors: unused
//   end - 1 sector:  E10 reserved
//
// RP2350's SDK default places Bluetooth bank 0 at the same offset as the
// existing Permanent Store. The project configuration relocates the RP2350
// Bluetooth banks while retaining the established OpenAce store addresses.
// SEE PICO_FLASH_BANK_STORAGE_OFFSET in config.hpp.in

constexpr size_t PERMSTORE_NUM_SECTORS = (VOL_DATA_SIZE + FLASH_SECTOR_SIZE - 1) / FLASH_SECTOR_SIZE;
constexpr size_t BINSTORE_NUM_SECTORS = (sizeof(GATAS::BinaryStore) + FLASH_SECTOR_SIZE - 1) / FLASH_SECTOR_SIZE;

// Used to store Application Configuration
static FlashStore permanentStore{PERMSTORE_NUM_SECTORS * FLASH_SECTOR_SIZE, FLASH_SECTOR_SIZE * 3};
// Used to store runtime information not stored in permanent store, counters, id's etc...
static FlashStore binaryStore{BINSTORE_NUM_SECTORS * FLASH_SECTOR_SIZE, FLASH_SECTOR_SIZE * 4};

static GATAS::ThreadSafeBus<24> bus;

static Config config(bus, volatileStore, permanentStore, binaryStore, DEFAULT_GATAS_CONFIG);
volatile static bool loadIndicator = false;
volatile static int8_t ledStatusIndicatorPin = -1;

static bool hasHardwareConfiguration(const etl::string_view moduleName, const Configuration &config)
{
    if (moduleName.ends_with(etl::string_view("_0")))
    {
        return !config.pinMap(moduleName, moduleName.substr(0, moduleName.size() - 2)).empty();
    }

    return !config.pinMap(moduleName).empty();
}

static void load(const etl::string_view str, etl::imessage_bus &bus, Configuration &config, bool force = false)
{
    if (ledStatusIndicatorPin > -1)
    {
        gpio_put(ledStatusIndicatorPin, loadIndicator);
        loadIndicator = !loadIndicator;
    }

#if GATAS_DEBUG == 1
    struct HeapLogger
    {
        ~HeapLogger() { printf("\nFree: %d\n\n", xPortGetFreeHeapSize()); }
    } heapLogger;
#endif

    auto registeredModules = BaseModule::registeredModules();

    printf("\nLoading %s ... ", str.cbegin());

    if (registeredModules[str].hwCheck && !hasHardwareConfiguration(str, config))
    {
        BaseModule::setModuleStatus(str, GATAS::PostConstruct::HARDWARE_NOT_CONFIGURED);
        printf("not configured for this device, skipping ");
        return;
    }

    if (!(config.isModuleEnabled(str) || force))
    {
        printf("disabled ");
        disabled(str, config);
        return;
    }

    if (!registeredModules.contains(str))
    {
        printf("-> not Found ");
        return;
    }

    auto *module = loadModule(str, bus, config);

    if (!module)
    {
        printf("-> out of memory ");
        return;
    }

    printf("-> PostConstruct() ");
    auto result = module->postConstruct();
    if (result == GATAS::PostConstruct::OK)
    {
        BaseModule::setModuleStatus(str, module);
        printf("-> start() ");
        module->start();
    }
    else
    {
        BaseModule::setModuleStatus(str, result);
        printf("-> Unloading reason [%s] ", postConstructToString(result));
        // TODO: Find out why deleting a module
        // For some strange reason when deleting a module, I get a hard crash
        // delete module;
    }
}

static void loadModules(void *arg)
{
    (void)arg;

    CoreUtils::init();
    config.postConstruct();
    config.start();

    BaseModule::setModuleStatus(Configuration::NAME, &config);

    load(WifiService::NAME, bus, config, true);

    WifiService *client = (WifiService *)(config.moduleByName(config, WifiService::NAME));
    if (client != nullptr)
    {
        load(Webserver::NAME, bus, config, true);
        load(Bluetooth::NAME, bus, config, true);
    }
    load(AircraftTracker::NAME, bus, config, true);
    load(AceSpi::NAMES[0], bus, config, true);
    load(AceSpi::NAMES[1], bus, config, true);

    // Hardware timings, GPS and connectivity
    load(PicoRtc::NAME, bus, config, true);
    load(GpsDecoder::NAME, bus, config);
    load(UbloxM8N::NAME, bus, config);
    load(L76B::NAME, bus, config);
    load(Gdl90Service::NAME, bus, config);
    load(GDLoverUDP::NAME, bus, config);
    load(DataPort::NAME, bus, config);
    load(AirConnect::NAME, bus, config);
    load(GatasConnect::NAME, bus, config);
    load(GatasConnectUDP::NAME, bus, config);
    load(Bmp280::NAME, bus, config);

    load(RxDataFrameQueue::NAME, bus, config, true);
    for (uint8_t i = 0; i < GATAS_MAX_RADIOS; i++)
    {
        load(Sx1262::NAMES[i], bus, config);
    }
    // Other for these two are currently important to ensure configuration on TX is set before RX
    // see RadioTunerRx::enableDisableDatasources()
    // Data sources
    load(RadioTunerTx::NAME, bus, config);
    load(RadioTunerRx::NAME, bus, config);
    load(ADSBDecoder::NAME, bus, config);

    // Protocols
    load(ADSLAce::NAME, bus, config);
    load(FanetAce::NAME, bus, config);
    load(Flarm2024::NAME, bus, config);
    load(Ogn1::NAME, bus, config);
    load(Dump1090Client::NAME, bus, config);

    // Must be loaded last because some modules uses these to send messages to other modules and we need to ensure that all modules are loaded
    load(Idle::NAME, bus, config, true);

    // SerialADSB messes up the serial terminal, but it will load beyond this point
    // load(SerialADSB::NAME, bus, config);
    // puts("\033[2J\033[H");

    printf(
        R"=(

     █████████    █████████   ███████████   █████████    █████████
    ███░░░░░███  ███░░░░░███ ░█░░░███░░░█  ███░░░░░███  ███░░░░░███
   ███     ░░░  ░███    ░███ ░   ░███  ░  ░███    ░███ ░███    ░░░
  ░███          ░███████████     ░███     ░███████████ ░░█████████
  ░███    █████ ░███░░░░░███     ░███     ░███░░░░░███  ░░░░░░░░███
  ░░███  ░░███  ░███    ░███     ░███     ░███    ░███  ███    ░███
   ░░█████████  █████   █████    █████    █████   █████░░█████████
    ░░░░░░░░░  ░░░░░   ░░░░░    ░░░░░    ░░░░░   ░░░░░  ░░░░░░░░░

        GATAS Device ID: %lX

        )=",
        static_cast<uint32_t>(config.internalStore()->gatasId));
    gpio_put(ledStatusIndicatorPin, 1);

    vTaskDelete(nullptr);
}

#if configGENERATE_RUN_TIME_STATS == 1 && configSHOW_RUN_TIME_STATS == 1
namespace
{
    struct PreviousTaskRuntime
    {
        TaskHandle_t handle;
        configRUN_TIME_COUNTER_TYPE runTimeCounter;
    };

    const char *taskStateToString(const eTaskState state)
    {
        switch (state)
        {
        case eRunning:
            return "Run";
        case eReady:
            return "Ready";
        case eBlocked:
            return "Block";
        case eSuspended:
            return "Susp";
        case eDeleted:
            return "Del";
        case eInvalid:
        default:
            return "Inv";
        }
    }

    configRUN_TIME_COUNTER_TYPE previousRunTimeForTask(const PreviousTaskRuntime *entries,
                                                       const UBaseType_t numEntries,
                                                       const TaskHandle_t handle)
    {
        for (UBaseType_t i = 0; i < numEntries; i++)
        {
            if (entries[i].handle == handle)
            {
                return entries[i].runTimeCounter;
            }
        }

        return 0;
    }

    bool isFreeRtosIdleTask(const char *taskName)
    {
        return strncmp(taskName, "IDLE", 4) == 0;
    }
} // namespace

void vDiagnosticsTask(void *pvParameters)
{
    (void)pvParameters;
    configRUN_TIME_COUNTER_TYPE previousTotalRunTime = 0;
    PreviousTaskRuntime *previousTaskRuntimes = nullptr;
    UBaseType_t previousNumTasks = 0;

    while (true)
    {
        UBaseType_t numTasks = uxTaskGetNumberOfTasks();
        TaskStatus_t *taskStatusArray = static_cast<TaskStatus_t *>(pvPortMalloc(numTasks * sizeof(TaskStatus_t)));

        if (taskStatusArray)
        {
            configRUN_TIME_COUNTER_TYPE totalRunTime = 0;
            numTasks = uxTaskGetSystemState(taskStatusArray, numTasks, &totalRunTime);

            qsort(taskStatusArray, numTasks, sizeof(TaskStatus_t), [](const void *a, const void *b)
                  { return strcasecmp(((TaskStatus_t *)a)->pcTaskName, ((TaskStatus_t *)b)->pcTaskName); });

            const configRUN_TIME_COUNTER_TYPE deltaTotalRunTime =
                (totalRunTime >= previousTotalRunTime) ? (totalRunTime - previousTotalRunTime) : 0;
            const float windowSeconds = static_cast<float>(deltaTotalRunTime) / 1000000.0f;
            const float windowCapacitySeconds = windowSeconds * static_cast<float>(configNUMBER_OF_CORES);
            configRUN_TIME_COUNTER_TYPE idleWindowRunTime = 0;

            for (UBaseType_t i = 0; i < numTasks; i++)
            {
                const configRUN_TIME_COUNTER_TYPE previousRunTime =
                    previousRunTimeForTask(previousTaskRuntimes, previousNumTasks, taskStatusArray[i].xHandle);
                const configRUN_TIME_COUNTER_TYPE deltaRunTime =
                    (taskStatusArray[i].ulRunTimeCounter >= previousRunTime)
                        ? (taskStatusArray[i].ulRunTimeCounter - previousRunTime)
                        : 0;

                if (isFreeRtosIdleTask(taskStatusArray[i].pcTaskName))
                {
                    idleWindowRunTime += deltaRunTime;
                }
            }

            const float idleSystemPercent =
                (deltaTotalRunTime > 0)
                    ? (100.0f * static_cast<float>(idleWindowRunTime) /
                       (static_cast<float>(deltaTotalRunTime) * static_cast<float>(configNUMBER_OF_CORES)))
                    : 0.0f;
            const float busySystemPercent = 100.0f - idleSystemPercent;

            puts("\033[2J\033[H");
            printf("Task snapshot: %lu tasks | Heap free %lu / %lu bytes | CPU window %.2f s on %u cores (%.2f core-s)\n",
                   static_cast<unsigned long>(numTasks),
                   static_cast<unsigned long>(getFreeHeap()),
                   static_cast<unsigned long>(getTotalHeap()),
                   windowSeconds,
                   static_cast<unsigned int>(configNUMBER_OF_CORES),
                   windowCapacitySeconds);
            printf("System load: Busy %.2f%% | FreeRTOS idle %.2f%%\n", busySystemPercent, idleSystemPercent);
            puts("Note: BootC%/WinC% are relative to one core, so totals can exceed 100% on this dual-core SMP build.");
            puts("      WinSys% is relative to total CPU capacity across both cores. DiagTask can spike when printing.");
            puts("Task Name        Boot us     BootC%  Win us      WinC%   WinSys% State  Pri  Stack Left");
            puts("-------------------------------------------------------------------------------------------");

            for (UBaseType_t i = 0; i < numTasks; i++)
            {
                const configRUN_TIME_COUNTER_TYPE previousRunTime =
                    previousRunTimeForTask(previousTaskRuntimes, previousNumTasks, taskStatusArray[i].xHandle);
                const configRUN_TIME_COUNTER_TYPE deltaRunTime =
                    (taskStatusArray[i].ulRunTimeCounter >= previousRunTime)
                        ? (taskStatusArray[i].ulRunTimeCounter - previousRunTime)
                        : 0;
                const float bootPercent =
                    (totalRunTime > 0)
                        ? (100.0f * static_cast<float>(taskStatusArray[i].ulRunTimeCounter) / static_cast<float>(totalRunTime))
                        : 0.0f;
                const float windowPercent =
                    (deltaTotalRunTime > 0)
                        ? (100.0f * static_cast<float>(deltaRunTime) / static_cast<float>(deltaTotalRunTime))
                        : 0.0f;
                const float windowSystemPercent =
                    (deltaTotalRunTime > 0)
                        ? (100.0f * static_cast<float>(deltaRunTime) /
                           (static_cast<float>(deltaTotalRunTime) * static_cast<float>(configNUMBER_OF_CORES)))
                        : 0.0f;

                printf("%-16s %-11lu %-7.2f %-11lu %-7.2f %-7.2f %-6s %-4lu %-10lu\n",
                       taskStatusArray[i].pcTaskName,
                       static_cast<unsigned long>(taskStatusArray[i].ulRunTimeCounter),
                       bootPercent,
                       static_cast<unsigned long>(deltaRunTime),
                       windowPercent,
                       windowSystemPercent,
                       taskStateToString(taskStatusArray[i].eCurrentState),
                       taskStatusArray[i].uxCurrentPriority,
                       uxTaskGetStackHighWaterMark(taskStatusArray[i].xHandle));
            }

            PreviousTaskRuntime *currentTaskRuntimes =
                static_cast<PreviousTaskRuntime *>(pvPortMalloc(numTasks * sizeof(PreviousTaskRuntime)));

            if (currentTaskRuntimes)
            {
                for (UBaseType_t i = 0; i < numTasks; i++)
                {
                    currentTaskRuntimes[i].handle = taskStatusArray[i].xHandle;
                    currentTaskRuntimes[i].runTimeCounter = taskStatusArray[i].ulRunTimeCounter;
                }

                if (previousTaskRuntimes)
                {
                    vPortFree(previousTaskRuntimes);
                }

                previousTaskRuntimes = currentTaskRuntimes;
                previousNumTasks = numTasks;
                previousTotalRunTime = totalRunTime;
            }

            vPortFree(taskStatusArray);
        }

        uint32_t notifyValue = 0;
        xTaskNotifyWait(pdFALSE, ULONG_MAX, &notifyValue, TASK_DELAY_MS(5'000));
    }
}
#endif

//  WifiService::PostConstruct()...assertion "get_core_num() == async_context_core_num(cyw43_async_context)" failed: file "/opt/pico/pico-sdk/src/rp2_common/pico_cyw43_driver/cyw43_driver.c", line 54, function: cyw43_irq_init
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
int main()
{
    bool at200Mhz = false;
    if (set_sys_clock_khz(200000, true))
    {
        at200Mhz = true;
    }
    stdio_init_all();
    overflowTest();

#if GATAS_DEBUG == 1
    etl::error_handler::set_callback<etlcpp_receive_error>();
#endif

    const char *rtos_name;
#if (configNUMBER_OF_CORES > 1)
    rtos_name = "GaTas FreeRTOS SMP";
#else
    rtos_name = "GaTas FreeRTOS";
#endif

#if (configNUMBER_OF_CORES > 1)
    printf("        Starting %s on both cores at %dMHZ:\n\n", rtos_name, at200Mhz ? 200 : 125);
    vLaunch();
#elif (RUN_FREERTOS_ON_CORE == 1)
    printf("        Starting %s on core 1:\n\n", rtos_name);
    multicore_launch_core1(vLaunch);
    while (true)
    {
        ;
    }
#else
    printf("        Starting %s on core 0 %dMHZ:\n\n", rtos_name, at200Mhz ? 200 : 125);
    vLaunch();
#endif

    return 0;
}

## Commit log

2024-09-15 organise build script fix bug in wifiservice
    [main.cpp]
2024-09-29 Added PCB v0.0.2 design file
    [2985-6038.STEP, CONSMA002--3DModel-STEP-1.STEP, OpenACE V0.0.2.kicad_pcb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]
2024-09-30 Add OpenSCAD design and documentation
    [ImageToStl.com_openace.stl, OpenACE V0.0.2.kicad_pcb, openace_v0.0.2.scad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]
2024-10-11 Added 868Mhz Antenna array design Added GPS holder that can be attached on the enclosure
    [868Mhz-antenna-array.scad, gps-antenna-holder.scad, openace_v0.0.2.scad]
2024-10-12 Updated gps-antenna-holder to make it easer to print
    [gps-antenna-holder.scad, openace_v0.0.2.scad]
2024-10-14 Added tests for adsl Add compile flags to fail on error, and fix code within
    [main.cpp]
2024-10-15 Modulair GPS antenna
    [gps-antenna-holder.scad]
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2024-10-18 Update GPS Antenna
    [gps-antenna-holder.scad]
2024-10-19 Add build timestamp in UI Ran prettier on ui code Better handle when serial TX fails in ublox code sx1262_hal now uses vTaskDelay(..) instead of taskYIELD WifiService will force stop scanning after 1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
    [main.cpp]
2024-10-28 Get geoidOffset from GPS, but also add option to get the geoidOffset by code, just in case.. Tests that OGN and ADSL are received
2024-10-30 Added cdebyte E108 GN04 Antenna design in enclosure.
    [gps-antenna-holder.scad]
2024-11-01 Allow GPS on a LID
    [gps-antenna-holder.scad, openace_v0.0.2.scad]
2024-11-08 Fix KiCAD v0.0.2 PCB
    [OpenACE V0.0.2.kicad_pcb]
2024-11-08 Allow for enable/disable interrupt Coreutils to get a raw 32bit us timer Fix timing on all protocols + additional tests Ensure radio's don;t switch protocols once assigned SX1262 HAL better buzy time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
    [main.cpp]
2024-11-09 Fix issue where reception of multiple protocols did not always work as expected Optimised protocol distribution on available radio's Simplify Sx1262::configureSx1262, this was not a lot of time saved
    [main.cpp]
2024-11-09 Sinplify the case
    [openace_v0.0.2.scad]
2024-11-09 GPS on top of the case design, that is rotatable.
    [gps-antenna-holder.scad]
2024-11-13 test acquire for a mutex for modules simplify acquire access to the spi bus making it sync instead of with callback
2024-11-15 Added option to place the tocker switch in the LID
    [openace_v0.0.2.scad]
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2024-11-17 Add CRITICAL section in the interrupt routine Add acquireSlotSyncCb that allows for a delegate to be passed webserver statistics for memory alloc errors
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2024-11-18 Send Idle Message over the message bus re-organise LWiP config for better upgrades Fix pesky MEMP_SYS_TIMEOUT messages that sometimes happened bmo280 will use IdleMsg instead of it's own task to get 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
    [main.cpp]
2024-12-01 Fix topGNSS case
    [gps-antenna-holder.scad]
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2024-12-13 Code Cleanup
    [openace_v0.0.2.scad]
2024-12-15 Added initial code for DataPort + AirConnect Renamed all Message bus message so they end with the suffix Msg AccessPoint or Wifi CLient did not send correct connect/disconnect messages
    [main.cpp]
2024-12-17 Furter optimise AirConnect + Removal of potential nullpointer Prevent Ublox of sending GPGS[AV] in the messagebus, this will lower resources and they ar e not processed anyways. Start work on (Datapo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
    [main.cpp]
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2024-12-28 Code cleanup Add bluetooth BLE and Classic (RFComm) for Dataport Fixed semaphoreguard and how it was used Add type deduction in CircularBuffer for get and peek
    [main.cpp]
2025-01-04 Update bluetooth due to pairing issues. Moved flash store to a different location due to bluetooth bonding location. Updated UI so a user can set the vluetooth device name
    [main.cpp]
2025-01-06 Re-Added __scratch_y data arrays Added RFCOMM / SPP for bluetooth Added CYW43_ to prevent Stack Overflows? Still not sure
    [main.cpp]
2025-01-19 Better baudrate detection on ublox Cleanup of uart_rx_f.h Fix bluetooth configuration and removed deprecated functions
    [main.cpp]
2025-01-25 don't panic if module not found Renamed GpsTimeMsg to UtcTimeMsg to avoid confusion on what time reference it is. Handle potentional NAN from NMEA
    [main.cpp]
2025-02-01 Prepare for different GPS devices Cleanup FreeRTOS tasks Removed a few unneeded filters in gpsdecoder Add statistics in dataport
2025-02-07 Add configuration for Waveshare Lite Hardware Don't attempt to load HW whe not supported Hardware pins are now directly loaded from the hw module Added support for Waveshare L76B GPS module Added sup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
    [OpenACE V0.0.2.kicad_pcb]
2025-02-08 Forgot to add the L76B GPS code Verified GPS sync for L76B
    [gps-antenna-holder.scad]
2025-02-11 Design for the TopGNSS GPS Antenna
    [gps-antenna-holder.scad]
2025-02-12 Design for the TopGNSS GPS Antenna Force handling queue when RMC is received
    [gps-antenna-holder.scad]
2025-03-02 FANET Tests
    [openace_v0.0.2.scad]
2025-03-02 Missing SPI numbering for 'pin' map
2025-03-30 Experimental FANET
    [openace_v0.0.2.scad]
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2025-04-06 Fix generated default config
    [main.cpp]
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2025-04-13 Re-Enabled testing Updated doc Set faster time in RTC after reboot when GPS is known More robust handling of FLARM when there are time offsets
    [main.cpp]
2025-05-02 Added capability for a Android/iOS Companion application to receive ADSB Data Small fix on the aircraft tracker Cleanup bluetooth handling.
    [main.cpp]
2025-05-09 Changes startup sequence for faster startup and reconnect Fix issue on circularbuffer Removed Timer on the aircrafttracker
    [main.cpp]
2025-05-26 Added initial design of the OpenAce Pulse Version
    [RaspberryPi-PicoW-WithPins.step, RaspberryPi-PicoW-WithPins.stl, openace_Pulse.scad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]
2025-05-28 Work OpenAce Pulse version
    [openace_Pulse.scad, parts.scad]
2025-06-08 Update STL's / SCAD for build instructions wiki
    [gatas_Pulse.scad, gatas_Pulse.stl, gatas_v0.0.2.scad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]
2025-06-16 Revisit internal height/altitude handling changed to ellipsoid for all protocols internally Enable external LED to blink Update web interface GA/TAS Companion compatibility Cleanup of Radio
    [868Mhz-antenna-array.scad]
2025-06-28 US a specific DataFrame queue to receive packets to offload the transceiver Small UI changes Code cleanup on how to set the protocols order Removed tasks from 3 protocols because the FrameQueue can b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
2025-07-06 Send the protocol Config as a pointer to reduce copying memory around Remove the coding rate from RadioParameters, this can be decided during transmissions and there is no need to keep a default New 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
    [main.cpp]
2025-07-14 Added additional tests for Config module Added IdleMsg, Every5SecMsg, Every15SecMsg, Every30SecMsg so modules don't have to keep track of their own method to do something every once a while Prepare B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
    [gatas_Pulse.scad]
2025-08-08 Fix: Correct various spelling and grammar errors (#3)
    This commit addresses multiple spelling and grammatical mistakes found in the project's documentation, user interface, and source code comments.
    The corrections improve the overall readability and professionalism of the codebase.
    Changes were made in the following files:
    - README.md
    - doc/heights.md
    - src/lib/flarmgatas/doc/nmi71bTG.md
    - src/lib/radiotuner/readme.md
    - src/lib/sx1262/driver/CHANGELOG.md
    - src/SystemGUI/captive/captive.html
    - src/SystemGUI/src/components/aircraftconfig.js
    - src/SystemGUI/src/components/gpsstatus.js
    - src/SystemGUI/src/components/moduleconfigs.js
    - src/SystemGUI/src/components/modules.js
    - src/SystemGUI/sr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
    [main.cpp]
2025-09-13 GA/TAS Connect Connectivity (#4)
    Add badge
    Working version GA/TAS Connect - gatasServer will be uploaded soon after cleanup of code
    Renaming of variables for clarification
    Ensure specific messages have long mutex timeouts because they are important
    Added gatasId needed for gatasServer to re-Configure devices
    Allow to see your local GA/TAS IP address from GA/TAS server
    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
2025-10-12 Various (#5)
    * Wrong place transmission counter
    * Better respond to interface changes
    Only init mDNS once
    * Fix GLD90 when GATAS connects to a phone running an EFB
    * Align WIFI password rules with firmware to 20 chars
    Always enable Bluetooth
    * Re-visit BlueTooth handling
    Add a new packetBuffer class that will handle whole packets only
    Optimise TrackerData sends messages for aircrafts that need to be processed by attached devices
    * Removed CircularBuffer
    Removed StreamBuffer
    Created TCPCLient wrapper around LWiP
    Created Gulp class to help with reading streamed packages
    Created PacketByffer to help with writing packages
    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
    [openace.step]
2025-10-26 Removed 'stop' virtuals. Reboot is fast enough (#7)
    Further tuned LWiP Stack
    Make use of __scratch_y on the PICO
    Changed data copy to use a spinlock rather than a mutex fort critical structures
    [main.cpp]
2025-11-03 Remove Idle Message into it's seperat emodule Introduced a LED blinking pattern to indicate status of GATAS for GPS and Network using PICO's Alarms to not usee FreeRTOS Delays.
2025-11-07 Correctly de-initialise on WIFI change Show small aircraft instead of UNKNOWN to avoid UNKNOWN aircraft to be shown in the EFB. Might need a bit of extra research to further avoid this. It seems to b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
    [main.cpp]
2025-11-12 Include Satellites in View for GPS
    [gatas_Pulse.scad]
2025-11-14 Fix WifiServers in AP mode where the IP was not found correvtly in cyw43_state.netif Fix for initial Load anf store in flash outside of a FreeRTOS TASK Build uf2 file with the name of the platform Op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
    [main.cpp]
2025-11-24 GDL90 now does auto discovery for ForeFlight (to be tested, but looks good) Updated stl for Pulse version such that people don't have to split it anymore Better GATAS_LOG that logs FILE and LINE numb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
    [gatas_Pulse.scad, gatas_Pulse.stl]
2025-12-06 Dump version number L76B in Debug Mode Fix: When WIFI Service does nto have any configured clients, but AP mode only set, ensure we still start a AP
    [gps-cdbyte-e108-GN04-holder.stl, gps-holder-cdbyte-e108-gn04.stl]
2025-12-13 Allow to pu GATAS in AP mode from the UI Set the Airplane page as the default page and added the Actions Buttons in that page Updated DDB
2026-03-04 ADSL Issue 2 implementation (#12)
    * ADSL Issue 2 implementation
    * Fix FLARM sending and receiving
    * Fix RP2350 builder server FreeRTOS Patch
    [main.cpp]
2026-04-13 Groundstation mode
    * Groundstation mode
    * Fix regression FANET
    * Update GATAS naming
    * Slowdown TX when plane is stationary
    * Fixed device error SX1262
    * Updated TX Timing and visualisations
    * Guards around a few containers
    * code cleanup
    * Use xTaskNotifyWait instead of ulTaskNotifyTake
    * Set Lower power mode to a slightly higher dBm for testing
    * code cleanup
    * Allow per protocol TX, RX or RX/TX
    * Code Cleanup, fix random time issue.
    * Show Traffic in Aircraft Data
    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
    [868Mhz-antenna-array.scad, gatas_Pulse.scad]
2026-04-28 Improved flarm reception (#16)
    * Fix antenna pattern to be relative to aircraft
    * Track in FLARM if CRC corrections where performed
    [main.cpp]
2026-04-30 - Better rendering of RadioTUnerTX and Protocol Timing in the UI (#17)
    Better rendering of RadioTUnerTX and Protocol Timing in the UI
    Moved the 'action' buttons to a seperate page in the UI
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2026-07-14 Tracker (#23)
    * Aircraft Tracker
    Code Cleanup
    * Include Path PRedication
    * fix merge conflicts
    * - Experimental aircraft path prediction in `AircraftTracker`, using recent position, speed, heading, vertical speed, and turn-rate history to extrapolate short gaps in tracked traffic.
    - Desktop test coverage for aircraft path prediction and updated antenna-radiation bearing behavior.
    - Added an `AircraftTracker` configuration and web UI option to enable or disable path prediction.
    - `AircraftTracker` now keeps lightweight predictor state for nearby traffic and can forward extrapolated positions during scheduled client updates.
    - Normalized several tracker/core numeric types and math helpers,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
    [main.cpp]
2026-08-06 * Fix for incorrectly shown aircraft. Storage in GATAS was correct.
    [main.cpp]
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
